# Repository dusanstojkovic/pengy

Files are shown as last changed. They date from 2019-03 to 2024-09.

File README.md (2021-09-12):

# Air Quality Monitoring



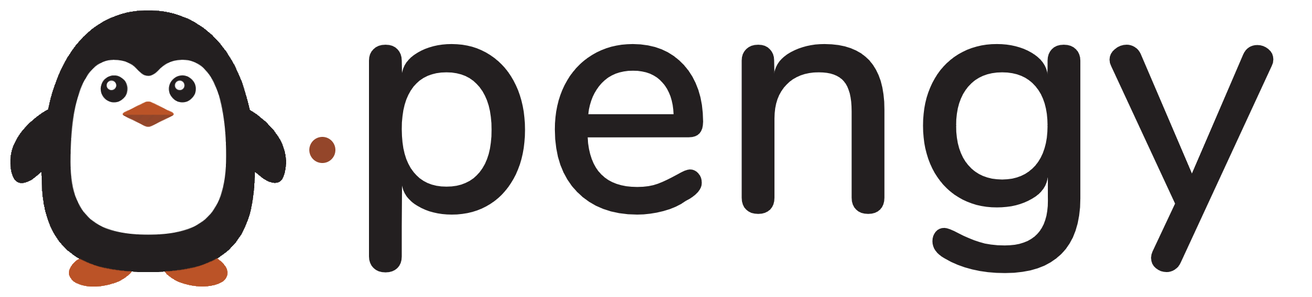
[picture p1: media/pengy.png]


**Pengy** is the system for monitoring of the air quality parameters.

The system concept and how it is build are described in the personal blog [quo.vadis.stojkovic.ch](https://quo.vadis.stojkovic.ch/air-pollution-monitor/)

## Description

The sensors on the nodes are measuring the relevant air parameters (t, RH, p, PM1.0, PM2.5, PM10 ...), data is acquired with [*Heltec CubeCell (HTCC-AB01)*](https://heltec.org/project/htcc-ab01/) device and sent using *LoRaWAN* via *The Things Network* platform. Integration to *Thingy*, as well to *Sensor Community* and *Pulse.Eco* platforms, is used for the visualization of the results.

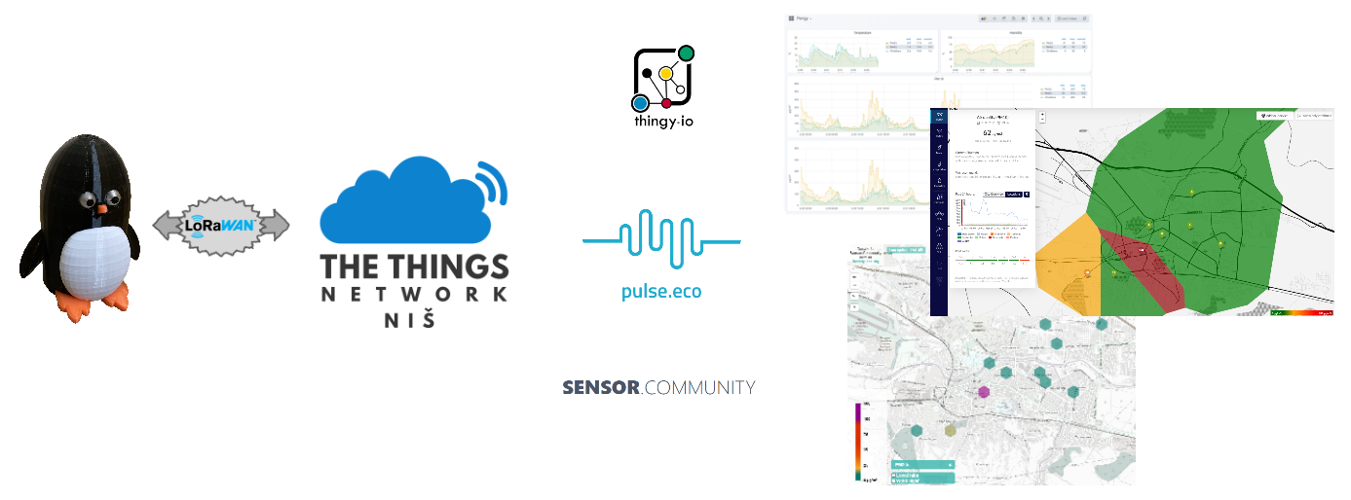
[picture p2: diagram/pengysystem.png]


Depending on the version, different sensors are used and different parameters are measured.
In the current version (2.0), parameters that are measured are: 
- air temperature (t)
- air relative humidity (RH)
- atmospheric pressure (p)
- environmental noise
- respirable (<10μm) particulate matter mass concentration (PM 10)
- fine (<2.5 μm) particulate matter mass concentration (PM 2.5)
- ultra fine (<1 μm) particulate matter mass concentration (PM 1)

using the following sensors:
- SPS30
- BME280
- MAX9814 amplifier based microphone

For the overview of the parameters and sensor used in previous version, refer to:
- version 1.5 - https://github.com/dusanstojkovic/pengy/tree/v1.5
- version 1.0 - https://github.com/dusanstojkovic/pengy/tree/v1.0

## Content

* In the folder [firmware](firmware/), you can find the latest firmware for a Pengy node
* Integration with *The Things Network* is in folder [ttn](integration/ttn/)
* Python script to push the data to *Sensor Community* platform is in folder [sensor.community](integration/sensor.community/)
* Python script to push the data to *Pulse.Eco* platform is in folder [pulse.eco](integration/pulse.eco/)
* STL files for 3D printing of the enclosure are located in folder [enclosure](enclosure/)
* Supporting pictures, drawings and diagrams you can find under [media](media/) folder
* Some additional documentation can be found under [misc](misc/) and [docs](firmware/docs/)

## Electrical schema, enclosure and assembly

There are only couples of the components that need to be soldered. Only basic soldering skills are required. Here is a simplified electrical schema:

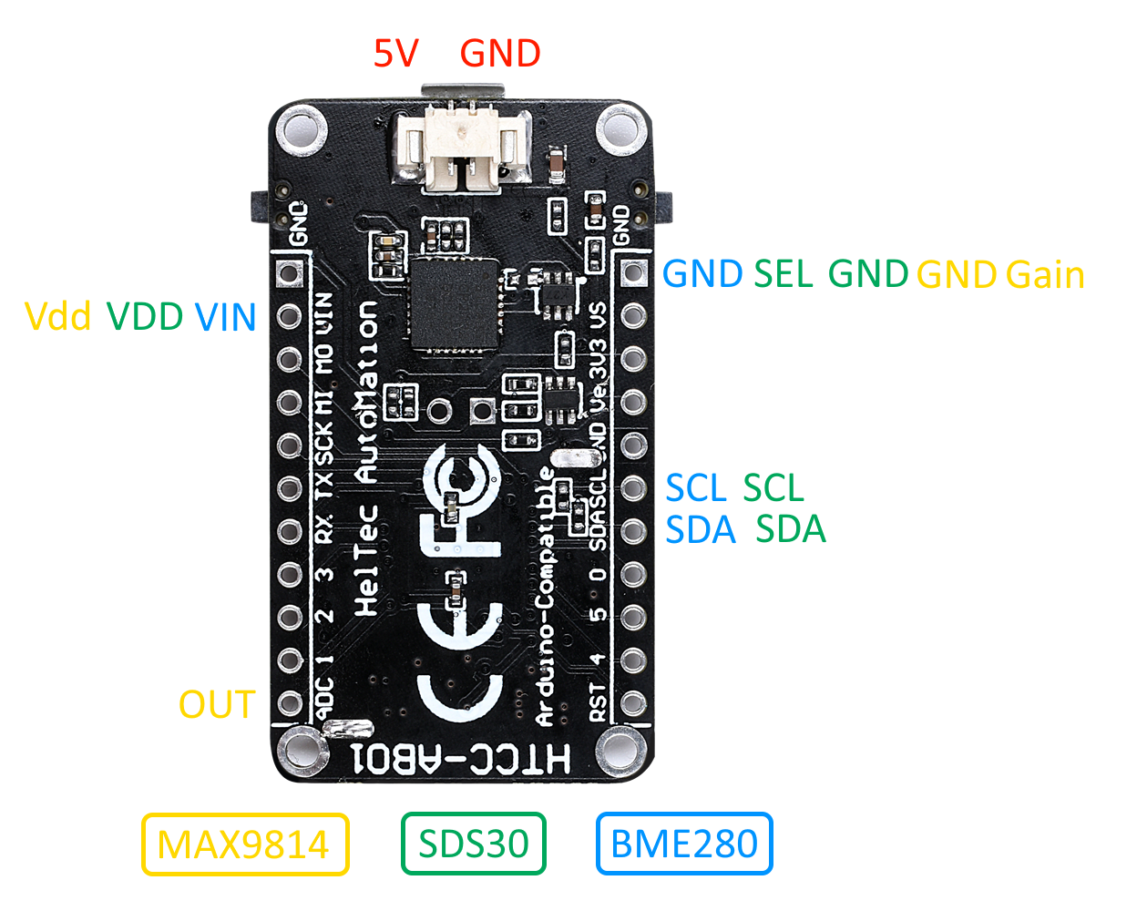
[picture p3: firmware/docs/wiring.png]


Keep in mind that 2 pull up resistors on I2C lines should be used for **SDS30**.

In this version of Pengy, there is the 3D printed enclosure available, which simplifies assembling of the whole sensor:

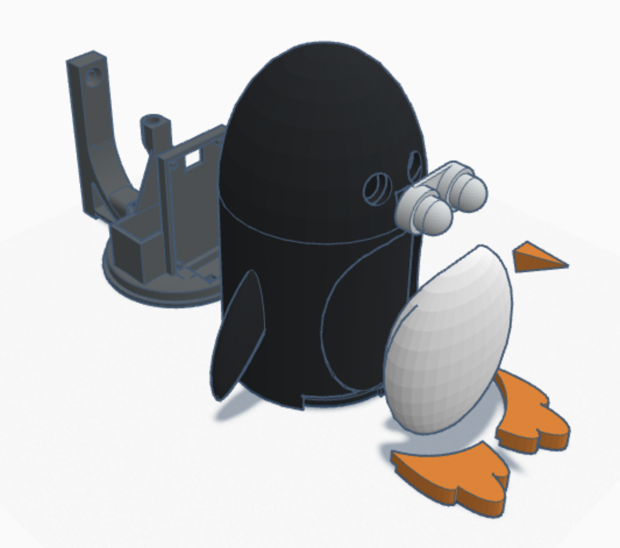
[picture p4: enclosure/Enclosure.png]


All files needed for 3D printing are located in folder  [enclosure](enclosure/). The whole design is also available on [Tinkercad](https://www.tinkercad.com/embed/jLOi4Yv6dmK) in case any modifications or adaptations needed.

The final assembly should be straightforward. There is a 'embedded' place for each electronic component modeled into the enclosure mount part. The rest of the enclosure parts can be glued together.

## EAQI - European Air Quality Index

One of the parameters that is calculated based on particulate matter concentrations measured is _European Air Quality Index_ - EAQI. More information about the index and methodology can be found http://airindex.eea.europa.eu/.

As a special feature, Pengy device would light up its eyes in the color that corresponds to the current air quality:

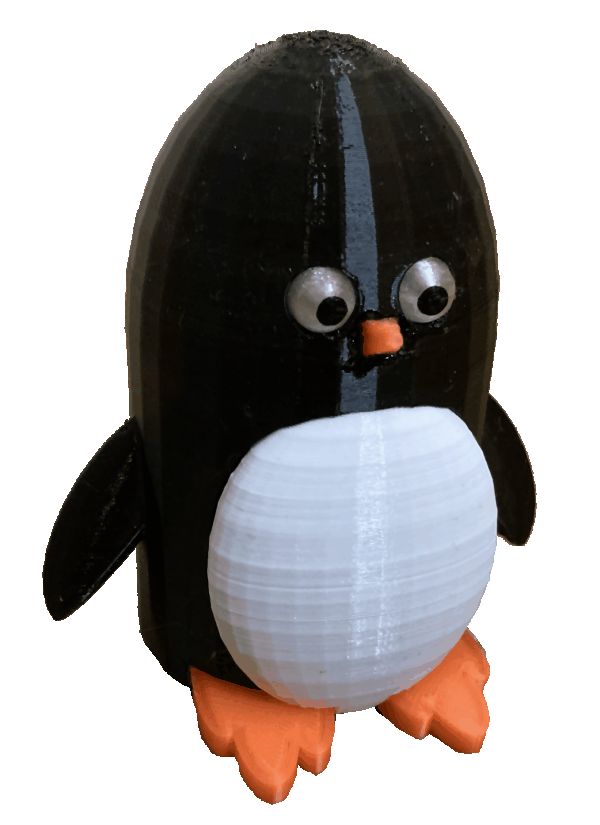
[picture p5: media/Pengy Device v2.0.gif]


## Additional information

More information regarding LoRaWAN and The Things Network can be found on their sites [LoRa Alliance](https://lora-alliance.org/about-lorawan) and [The Things Network](https://www.thethingsnetwork.org/).

More information about the contribution driven global sensor network  **Sensor Community** can be found here: [https://sensor.community/](https://sensor.community/)

More information about the environmental data crowdsourcing platform **Pulse.Eco** can be found here: [https://pulse.eco/](https://pulse.eco/)

## Notice
Due to the DIY nature of this system, the resulting measurements cannot be considered as more precise or accurate than the official measurement performed.

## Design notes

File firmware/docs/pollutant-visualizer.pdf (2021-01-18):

CHAPTER 1

INTRODUCTION

In the past decades there have been tremendous advancements in the field

of automobile industry. Usage of vehicle has been increasing rapidly. Impact on

the other side is increasing pollution level. According to European Pollution

Agency (EPA), India is generating pollution from automobiles equal to burning

of 200 million tonnes of coal every year.

This project is focussed on monitoring this pollution level to provide

awareness among people through public displays and open community maps.

System is broadly categorised into three parts: data acquisition unit, data posting

and finally data retrieving and visualizing. Data acquisition part is sub divided

into sensing unit and processing unit. In sensing unit there are two different

sensing elements which produce output levels based on gas concentrations and

suspended particles concentration (PM2.5 and PM10). As a rule of thumb,

sensors produce output in analogue form. This signal is given to microcontroller

to convert it in to digitized form using A/D converter. An algorithm applied on

these digitized data's to get the gas concentrations in terms of Parts Per Million

(PPM) and Micro gram per cubic meter (ug/m3). This sensing and converting

process is carried out for some sampling period (say 10 seconds) and average of

this is taken as result.

SIM 808 is used to post this data to cloud. It satisfies complete need of a

cellular modem because it contains on chip GPS for accessing location

information, GPRS to connect to the internet and GSM to make and receives

calls and SMS. This modem has software layer for several internet based

applications like FTP, HTTP, and TCP. So that it can access these layers by

passing AT commands. HTTP protocol is used for sending data to cloud. After

processing, the data are sent to cloud using Hyper Text Transfer Protocol. All data are sent with respect to their location where they monitored. A PHP

handler is written on the server side to handle requests that are made during data

posting. PHP handler retrieves data from HTTP requests and stores it in a

database for future analysis. An open community map with the help of Google

maps API was designed which shows the pollution level in the form of coloured

circles based on the location. Each colour defines pollution level as good,

acceptable, moderate, worst, unhealthy, and dangerous. The data are stored in a

database and it can generate periodic reports and perform some data analytics

for future prediction of pollution levels and compares it with present. In future

developments awareness can be made by public displays placed in remote

places.

CHAPTER 2

POLLUTANT VISUALIZER

### 2.1 INTRODUCTION

Air pollution level has been increasing rapidly, so there should be some

remedies made to avoid and overcome that. Fuel efficient vehicles proved in

reduction of pollution emission. One way to overcome this is to protect

ourselves. For that, people must be aware of their environment. One such

platform is bringing awareness among people. Description of this system is as

follows.

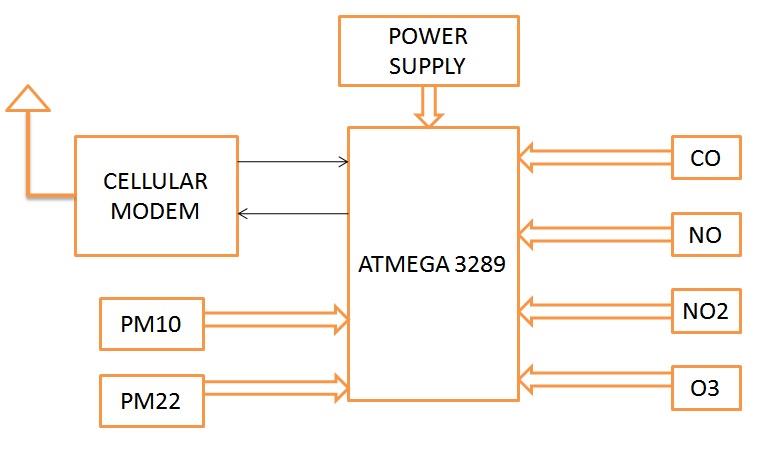
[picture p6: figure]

FIGURE 2.1 BLOCK DIAGRAM OF THE PROPOSED METHOD

### 2.1.1 DESCRIPTION

The block diagram shows ATMEGA 328 is used as a processing unit which

receives data from different sensors which produce outputs based on

concentration of gases such as Carbon Monoxide(CO), Nitrous Dioxide(NO2),

Ammonia(NH3) ,Ground ozone(O3) and suspended particles (PM2.5 and

PM10). A cellular modem SIM808 is connected to processing unit through

serial protocol (UART) and communicate with the server via this cellular

modem. A power supply unit which receives input from a battery of(6V-24V)

and uses two separate Low Drop Out (LDO) regulators for constant regulation.

One is for the cellular modem which dynamically varies the current

consumption when connected to internet and the other is for sensing and control

unit.

In hardware part, it has sensing elements which gives information about

environment (gas) in electrical form and microcontroller which does all

manipulations on acquired data. Starting with hardware part. Hardware part is

broadly categorized into five parts.

- Data Acquisition (Sensors)
- Processing unit
- Posting Unit

### 2.2 DATA ACQUISITION

The word 'electronic nose' is derived from the behaviour of today's

sensors. Humans can sense everything in physical environment. Humans have

nose which smell odours and can detect what it is. It works with the help of

olfactory glands which sense the smell and sends signal to brain through

Olfactory nerves. Brain tells you what type of smell it is by analysing that

signal. Same principle applies here. It has sensing elements which produce

signals based on gas presents in environment. Processing unit accepts these

signals, do manipulations and tells us the concentration of those gases.

### 2.3 PROCESSING UNIT

After passing signals through conditioning unit, the signal gets digitized

and processed in on-board microcontroller. ATMEGA 328 from atmel is used

as signal processing unit. It has its on-chip analog to digital converter unit with

10 bit resolution. So (0 – 5)V is scaled to (0-1024) in digital form. An algorithm

is applied on this digitized data to convert it into informative one. Several

sensors are connected to microcontroller as it is having multiple analog input

channels.

### 2.4 POSTING UNIT

Processing unit convert data into informative one like colour values based

on Air Quality index (AQI). These information will be send to our server

through a cellular modem SIM808. It is a single chip cellular modem supports

GPS, GSM and GPRS.

There is several gas sensing technologies in market. Each suits for

different applications and environments. Few of them are given below.

### 2.5 TYPES OF GAS SENSORS

Gas detectors are sensors that measure the concentration of a particular

gas in a particular area. Gas detectors are employed in many places like gas

leakage detection, indoor air quality monitoring, fire alarms etc. There are

different types of gas detectors which can measure and monitor combustible

gases, toxic and flammable gases. Carbon dioxide, carbon monoxide, Sulphur

dioxide, methane, ammonia are some common gases measured in industrial

applications.

Gas detectors:

- Electrochemical
- Metal oxide
- Infrared
- Pallister
- Semiconductor

### 2.5.1 ELECTROCHEMICAL

This method uses a chemical reaction for detecting the concentration of

gases. Its structure consist of Ion conductor sandwiched between two electrodes

(working electrode and counter electrode). When gases like carbon dioxide

(CO2) some kind of chemical reaction takes place in the working electrode. If

short occurs between working and counter electrode together then there will be

some flow of electrons between them. If connection is made through an external

wire there will also be electron flows through that. By placing an ammeter

current level which tells us the concentration of gas level is measured.

Current Flow

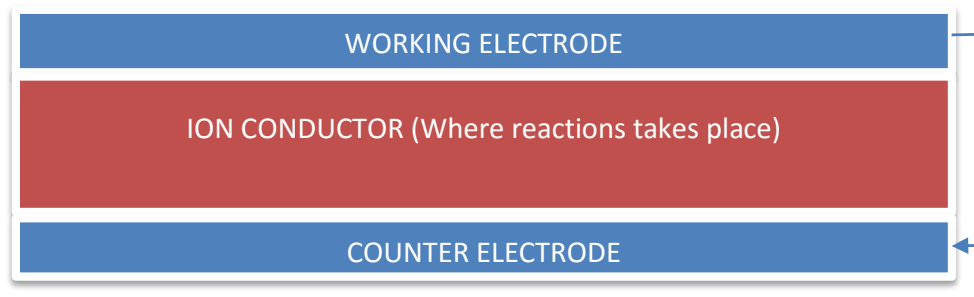
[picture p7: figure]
WORKING ELECTRODE; COUNTER ELECTRODE

FIGURE 2.2 ELECTROCHEMICAL SENSOR

### 2.5.2 METAL OXIDE

Tin oxide is used as a reactant and its surface is filled with absorbed

oxygen. The complete arrangement is placed above an alumina. In clean air

oxygen prevents the electron flow through this tin layer as it absorbs it. When

ION CONDUCTOR (Where reactions takes place) AMMETER any gas falls, reaction takes place and this absorb oxygen gets reduced. So

electrons starts to flow and it can be measured by placing an ammeter or load.

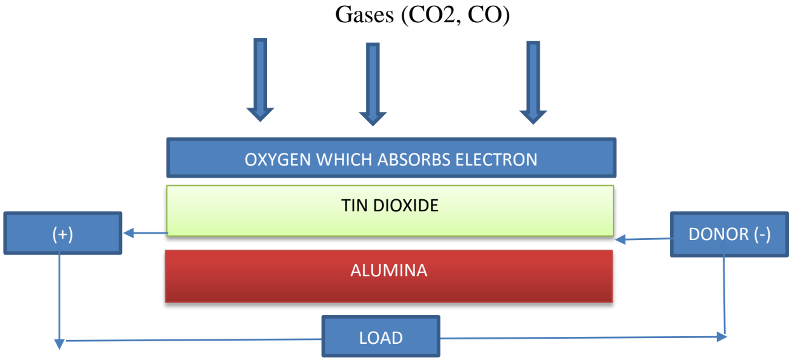
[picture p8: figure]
Gases (CO2, CO); OXYGEN WHICH ABSORBS ELECTRON; TIN DIOXIDE; ALUMINA; DONOR (-); LOAD

FIGURE 2.3 METAL OXIDE SENSOR

### 2.5.3 INFRARED (IR)

This method uses optical reflection technique to measure the gas

concentration level. Each gas absorb light of some wavelength. It depends on

type of gas that are going to measure. It consists of an infrared led and

photodiode arrangement. In clean air all the light get reflected back to

photodiode. When some gas falls on it then there will be some change in

received light and this difference in signal tells us the concentration of gases.

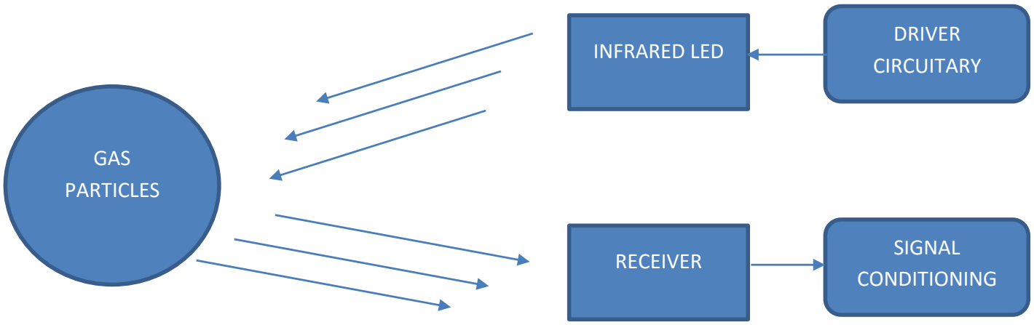
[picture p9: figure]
INFRARED LED; RECEIVER; GAS PARTICLES; DRIVER CIRCUITARY; SIGNAL CONDITIONING

FIGURE 2.4 INFRARED SENSOR

### 2.5.4 PALLISTER AND SEMICONDUCTOR

In this the detecting element consists of a pellet and a resistor. Selection

of a pellet depends on the gas that is going to be measured. Two beads called

active bead and reference bead. When gas comes in contact with these beads

active bead burns the gas and produces some heat which changes resistance.

Then it is compared with reference bead to determine the concentration of gas

applied.

Semiconductor method works on the same principle as pallister. Some

resistance change represent the concentration of applied gas. Tin dioxide is the

most common reactive material used in semiconductors. Common resistance

used with this type of sensor is 50 kilo ohm.

Among these types of sensors in the market Metal Oxide type is chosen

because it’s settling time is very fast and consumes very less power compared to

other types of sensors. Its reaction time is also too fast.

### 2.6 MICS 6814

Recent sensing technology utilize the power of metal oxides with the help

of semiconductor technology. Metal Oxides are Nano particles which today

takes place in most of Integrated Circuit fabrication technology. Micro Electric

Mechanical Systems (MEMS) mostly uses metal oxide in its fabrication in order

to decrease size and power consumption. MICS 6814 from SGX sensor tech is a

type of Metal Oxide type sensor which uses Zinc Oxide as a sensing element.

Working of metal oxide type gas sensing is show in picture below.

Gases (CO2, CO)

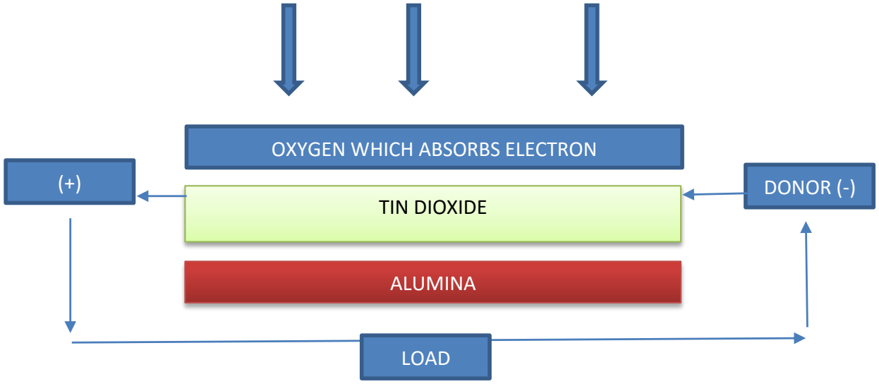
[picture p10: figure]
OXYGEN WHICH ABSORBS ELECTRON; TIN DIOXIDE; ALUMINA; DONOR (-); LOAD

FIGURE 2.5 MICS 6814

It consist of Zinc oxide which does not allow any current to pass through

it when pure oxygen falls on that. That is the resistance is infinity. When any

contaminated gas falls on that, amount of current which starts flow through that

and is directly proportional to concentration of fallen gas. By having different

sensing elements (heating elements) different type of gas concentration is

measured. MICS 6814 uses three different sensing elements in a single package

which can measure gases like carbon monoxide, nitrous dioxide, ammonia.

Heating element or substrate (RS) which combines with load resistor (RL)

forms a voltage divider. Heating element acts as a variable resistor based on

concentration of gases fallen. Output voltage swing varies depends on variable

resistor. Data manipulation section will provides enough information about how

these values are converted into microgram per cubic meter. Sensing element RS

which is a variable resistance and RO which is the resistance value measure

during calibration. Ratio of variable resistance (RS) to Initial resistance (RO)

tells us concentration of gas levels. Each sensing element has its own variable

resistance and calibration resistance which produces different ratio levels.

The figure below you the working principle of MICS6814, it contains

three different sensing elements (heating elements) for sensing the levels of

Carbon Monoxide, Nitrous Dioxide and ammonia. Each sensing element acts as

a variable resistor. It needs a load resistor to act as an active voltage divider

network. Thus output voltage varies proportional to the resistance of sensing

element.

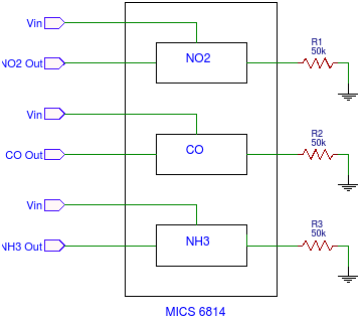
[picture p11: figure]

FIGURE 2.6 MICS WORKING

### 2.6.1 PERFORMANCE CHARACTERISTICS OF MICS 6814

Parameters which define sensitivity are RO (sensing resistance in air) and

RS (Sensing element). Sensitivity factor of variable resistance is given as SR.

Following table shows the specification of CO sensing element.

Sensing characteristics of CO sensor

Table 2.1 CO CHARACTERESTICS

Characteristic of CO sensor | Symbol | Typical | Minimum | Maximum | Unit
Sensing resistance in air | RO | - | 100 | 1500 | K ohm
Typical CO detection range | FS | - | 1 | 1000 | PPM
Sensitivity factor | SR | - | 1.2 | 50 | -

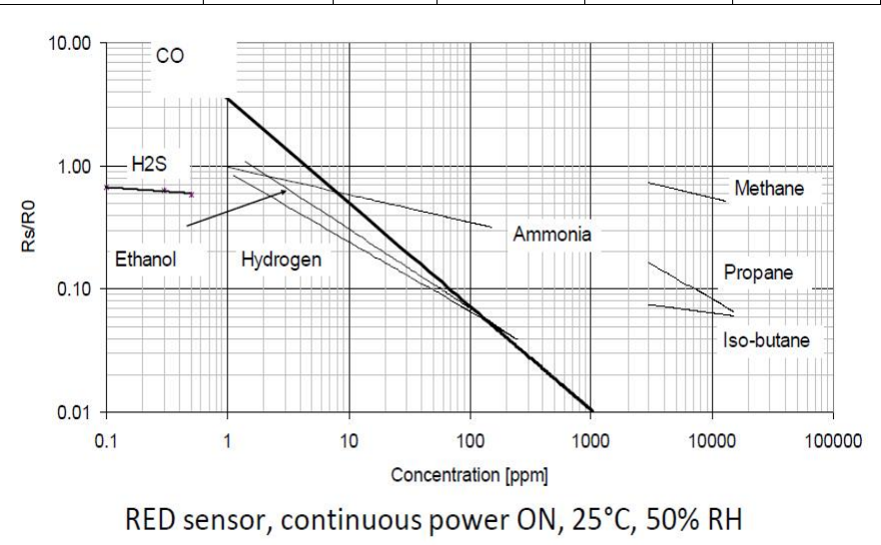
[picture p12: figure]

FIGURE 2.7 CO CHARACTERESTICS

Sensing characteristics of NO2 sensor

Parameters which define sensitivity are RO (sensing resistance in air) and

RS (Sensing element). Sensitivity factor of variable resistance is given as SR.

Following table shows the specification of NO2 sensing element.

Table 2.2 NO2 CHARACTERESTICS

Characteristic of CO sensor | Symbol | Typical | Minimum | Maximum | Unit
Sensing resistance in air | RO | - | 0.8 | 20 | K ohm
Typical CO detection range | FS | - | 0.05 | 10 | PPM
Sensitivity factor | SR | - | 2 | - | -

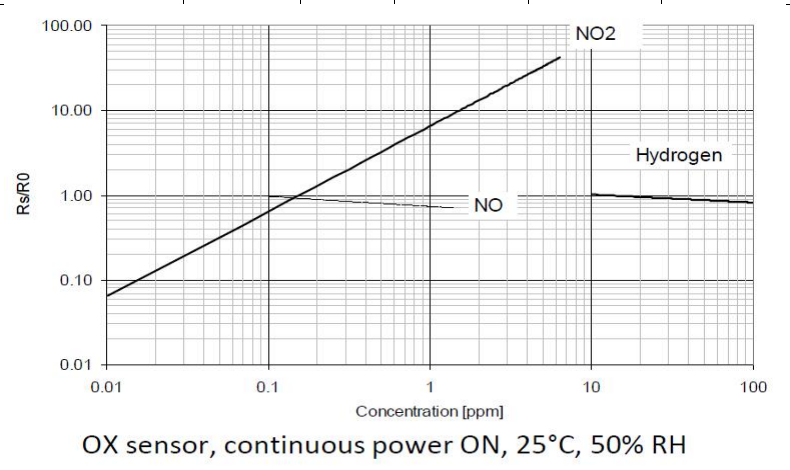
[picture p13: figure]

FIGURE 2.8 NO2 CHARACTERESTICS

Sensing characteristics of NH3 sensor

Parameters which define sensitivity are RO (sensing resistance in air) and

RS (Sensing element). Sensitivity factor of variable resistance is given as SR.

Following table shows the specification of NH3 sensing element.

Table 2.3 NH3 CHARACTERESTICS

Characteristic of CO sensor | Symbol | Typical | Minimum | Maximum | Unit
Sensing resistance in air | RO | - | 10 | 1500 | K ohm
Typical CO detection range | FS | - | 1 | 300 | PPM
Sensitivity factor | SR | - | 1.5 | 15 | -

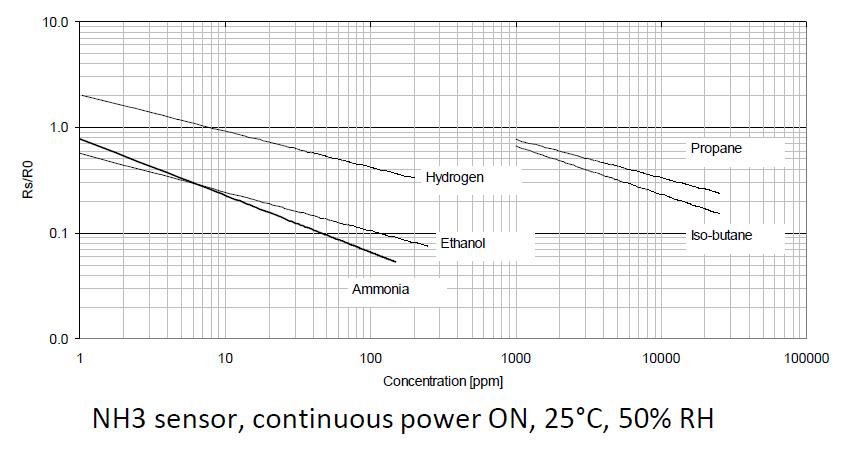
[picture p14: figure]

FIGURE 2.9 NH3 CHARACTERESTICS

Tables shows the detection range and sensitivity of each sensing

elements. Ro value can be taken from calibrating the sensor and Rs values is a

run time variable resistance value. Ratio of this will tells us the concentration.

Graphs shows how resistance ratio is related to gas concentrations in PPM.Line

equation for these graphs to find the relationship between ratio and PPM values

is found. By passing RS/RO into that line equation, concentration level in PPM

will be obtained.

### 2.6.2 ESTIMATION OF SENSITIVITY

First take two known points from the line to form an equation. Pass X and

Y values into line equation Y=Mx+C. Then by solving two known equations,

unknown value M that is slope can be found. Then by re arranging equation X

is found which is PPM in above graph by passing Y as Rs/Ro above.

Above process is carried for every sampling window and averaged value

is passed to following equation which results pollution level in microgram per

cubic meter.

PPB = PPM * 1000 | → Eq 2.1

Microgram per cubic meter = (PPM * 12.187 * M) / (273.15 + C) → Eq 2.2

Where,

M - Single molecule weight of gas.

C – Temperature in Degree Celsius.

### 2.6.3 MICS 6814 MODULE

A module from MGsuper labs is used which has it's on board controller to

receive analogue output from sensor. An algorithm which converts this raw data

into Parts per Million levels by having pre analysed data's provided by sensor

manufacturer. PPM values are taken from that module via Inter Integrated

Circuit as a communication interface. Complete block diagram of our module is

shown below.

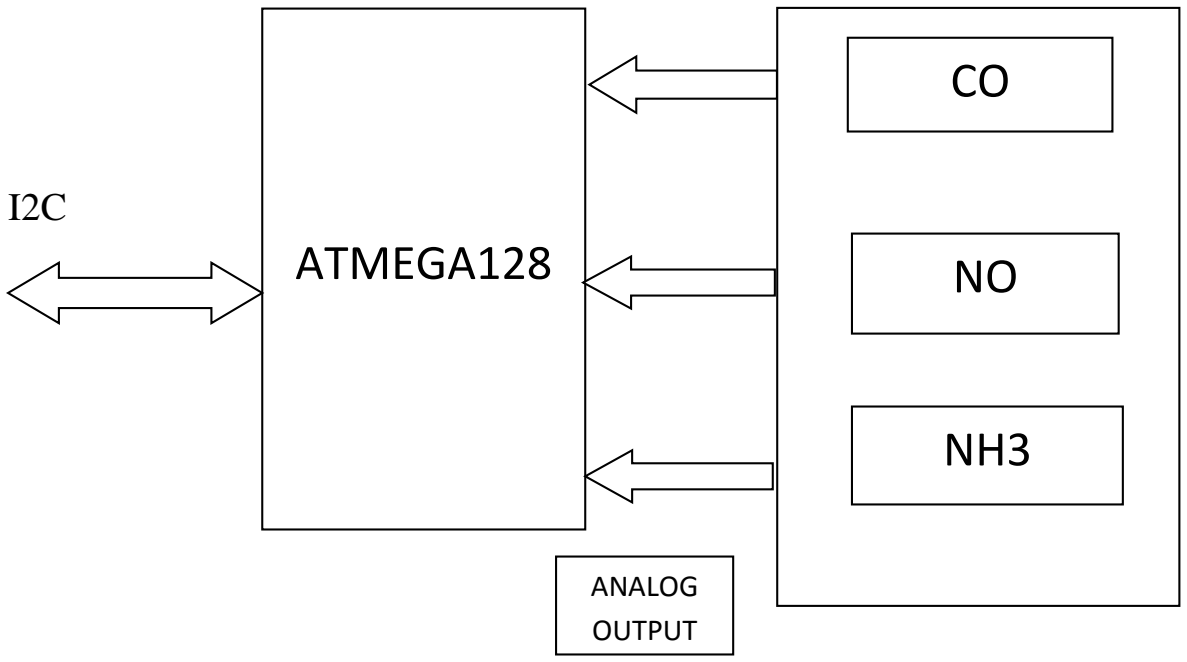
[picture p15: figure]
ATMEGA128; ANALOG OUTPUT

FIGURE 2.10 MICS 6814 MODULE DIAGRAM

ATMEGA 128 is an on board controller which continuously tells us the

concentration of sensed gases from device start up. It applies an algorithm that

will be discussed in software section to result the required values for further

manipulations. Data output is taken through I2C protocol for further processing.

### 2.7 MQ131

MQ131, a semiconductor type sensor capable of sensing ground ozone

level. Ozone present in ground will get react with hydrocarbons which causes

lung and asthma problems. It consist of a heating element which gets react with

ozone and changes its resistance proportional to ozone level present. The

working principle is as follows.

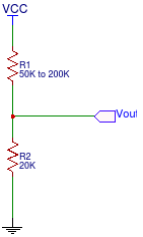
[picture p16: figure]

FIGURE 2.11 MQ131 WORKING PRICIPLE

Sensing element R1 varies between 50K - 200K. By connecting a load

resistor of 20K, the network acts as a voltage divider. So output voltage varies

depends on the resistance variation of this resistor R1. Specifications are given

below.

### 2.7.1 ELECTRICAL CHARACTERISTICS OF MQ131

TABLE 2.4 ELECTRICAL CHARACTERISTICS OF MQ131

Symbol | Parameter name | Level | Remarks
VH | Heating Voltage | 6V | DC
RL | Load Resistance | Variable | -

### 2.8 PARTICULATE MATTER MEASURING PRINCIPLE

Particulate matter otherwise called as suspended particles can be found in

air. They are in the form of dust, soot, smoke which cannot be seen by naked

eye. It contains two types of matters. One of them are ‘inhalable matters’ which

are less than 10 micro meter in size. Particles less than 2.5 micro meter comes

under ‘fine particle’ which can easily pass through deep lungs and cause health

problems. There are various techniques available in market for this particulate

matter measurement. Optical measurement is one of its type. It is very simple to

implement with high accuracy. It can be built with an Infrared transmitter, a

photodiode and its signal conditioning circuit.

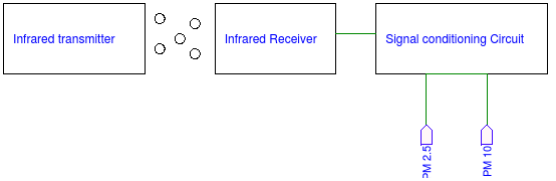
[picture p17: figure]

FIGURE 2.12 DUST SENSOR WORKING PRINCIPLE

Above block diagram simply explain working principle of optical type

particulate measurement technique. It consist of an Infrared transmitter which is

driven by constant current. Whenever dust particles comes in line of

transmission, then lights gets blocked. Photodiode receives this refracted light

and convert it into corresponding voltage by Transimpedance amplifier.

Converted voltage is compared with pre calibrated threshold voltage levels to

produce Pulse width Modulation (PWM) for both 2.5 and 10 micro meter dust

particles. Because light blocked by 2.5 micro meter particle is less than 10

micro meter particle. So two different threshold levels are used to differentiate

these two dust particles.

### 2.8.1 DUST SENSOR SM-PWM

Sm_PWM is a dust sensor that detects the dust particle concentration in

air by using optical sensing method. An infrared light emitting diode and a

photo sensor are optically arranged in the device. The photo sensor detects the

reflected light by dust particle in air. It can detect the small particles like

cigarette smoke and it can distinguish particles like smoke from large dust

particle by use of pulse pattern. Picture below show the working principle.

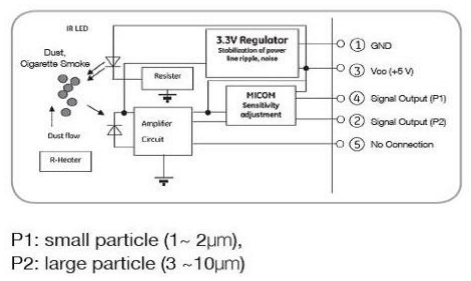
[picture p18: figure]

FIGURE 2.13 SM-PWM WORKING PRINCIPLE

The devices outputs two dust levels as a pulse modulated signal. Low

pulse period indicates the presence of dust particle. So for a sampling window

of 10 seconds time occupied by low pulse will tell you the percentage of dust

level present. Algorithm is discussed in software section later.

### 2.8.2 FEATURES

- Compact size, Light weight
- PWM output (Active low)
- Distinguishes small particles of cigarette smoke from large particles
- Low pulse is proportional to particle size
- Le.8.2 ad free and ROHS directive compliant

### 2.8.3 APPLICATIONS

- Detection of dust in air for indoor and outdoor air quality monitoring
- Air cleaners, Air purifiers, Air conditioners.
- Smoke type fire alarm.

### 2.8.4 ELECTRICAL CHARACTERISTICS

TABLE 2.5 ELECTRICAL CHARACTERISTICS OF DUST SENSOR

Parameter | Symbol | Rating
Supply Voltage | VCC | 0 – 7V
Operating Temperature | Toper | -10 – 70

### 2.9 MICROCONTROLLER ATMEGA 328

The ATmega48A/PA/88A/PA/168A/PA/328/P is a low-power CMOS 8-

bit microcontroller based on the AVR enhanced RISC architecture. By

executing | powerful | instructions | in | a | single | clock | cycle, | the

ATmega48A/PA/88A/PA/168A/PA/328/P achieves throughputs approaching 1

MIPS per MHz allowing the system designer to optimize power consumption

versus processing speed.

The AVR core combines a rich instruction set with 32 general purpose

working registers. All the 32 registers are directly connected to the Arithmetic

Logic Unit (ALU), allowing two independent registers to be accessed in one

single instruction executed in one clock cycle. The resulting architecture is more

code efficient while achieving throughputs up to ten times faster than

conventional CISC microcontrollers.

The ATmega48A/PA/88A/PA/168A/PA/328/P provides the following

features: 4K/8Kbytes of In-System Programmable Flash with Read-While-

Write capabilities, 256/512/512/1Kbytes EEPROM, 512/1K/1K/2Kbytes

SRAM, 23 general purpose I/O lines, 32 general purpose working registers,

three flexible Timer/Counters with compare modes, internal and external

interrupts, a serial programmable USART, a byte-oriented 2-wire Serial

Interface, an SPI serial port, a 6-channel 10-bit ADC (8 channels in TQFP and

QFN/MLF packages), a programmable Watchdog Timer with internal

Oscillator, and five software selectable power saving modes. The Idle mode

stops the CPU while allowing the SRAM, Timer/Counters, USART, 2-wire

Serial Interface, SPI port, and interrupt system to continue functioning. The

Power-down mode saves the register contents but freezes the Oscillator,

disabling all other chip functions until the next interrupt or hardware reset. In

Power-save mode, the asynchronous timer continues to run, allowing the user to maintain a timer base while the rest of the device is sleeping. The ADC Noise

Reduction mode stops the CPU and all I/O modules except asynchronous timer

and ADC, to minimize switching noise during ADC conversions. In Standby

mode, the crystal/resonator Oscillator is running while the rest of the device is

sleeping. This allows very fast start-up combined with low power consumption.

Atmel® offers the QTouch® library for embedding capacitive touch buttons,

sliders and wheels functionality into AVR® microcontrollers.

The patented charge-transfer signal acquisition offers robust sensing and

includes fully debounced reporting of touch keys and includes Adjacent Key

Suppression® (AKS™) technology for unambiguous detection of key events.

The easy-to-use QTouch Suite tool chain allows you to explore, develop and

debug your own touch applications. The device is manufactured using Atmel’s

high density non-volatile memory technology. The On-chip ISP Flash allows

the program memory to be reprogrammed In-System through an SPI serial

interface, by a conventional non-volatile memory programmer, or by an On-

chip Boot program running on the AV\R core. The Boot program can use any

interface to download the application program in the Application Flash

memory. Software in the Boot Flash section will continue to run while the

Application Flash section is updated, providing true Read While-Write

operation. By combining an 8-bit RISC CPU with In-System Self-

Programmable | Flash | on | a | monolithic | chip, | the | Atmel

ATmega48A/PA/88A/PA/168A/PA/328/P is a powerful microcontroller that

provides a highly flexible and cost effective solution to many embedded control

applications. The ATmega48A/PA/88A/PA/168A/PA/328/P AVR is supported

with a full suite of program and system development tools including: C

Compilers, Macro Assemblers, Program Debugger/Simulators, In-Circuit

Emulators, and Evaluation kits.

### 2.9.1 ARCHITECTURE

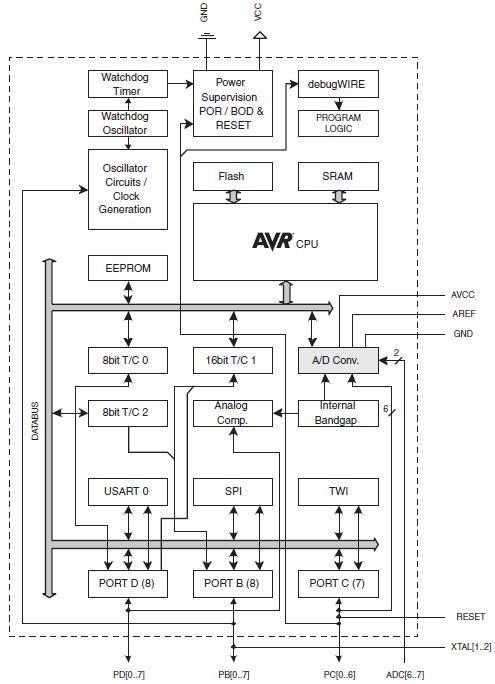
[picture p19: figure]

FIGURE 2.14 ATMEGA 328P ARCHITECTURE

### 2.9.2 ANALOG TO DIGITAL CONVERTER

To convert analog quantities into digital domain, A/D converters play a

major role. ATMEGA328 has a 10 bit, programmable sampling rate analog to

digital converter. It has eight analog input channels to interface as many

sensors. It has a full scale input of 5V and optional voltage reference pin to vary

the full scale input. Its output scale is from 0 to 1024. Four different channels

have been used to interface four different gas sensors. Each channel is

converted sequentially.

### 2.9.3 FEATURES

- High performance, Low power 8 bit microcontroller family
- Advanced RISC architecture
- 131 powerful instructions
- 32x8 general purpose working registers
- Fully static operation
- Up to 20 MIPS
- 32 Kilo bytes of flash memory
- 256 bytes of EEPROM
- 512 bytes of SRAM
- Programmable serial USART
- Master Slave SPI interface
- Six PWM channels
- Six channel 10 bit Analog to Digital converters
- On chip Analog converter
- Interrupt and wake up
- Power on reset
- Brown out reset
- Operating range – 1.8V to 5.5 V

- Operating frequency - 4 to 20 MHz

### 2.10 SIM808

SIM808 module is a complete Quad band GSM/GPRS module which

combines GPS technology for satellite navigation. The compact design which

integrated GPRS and GPS in a SMT package will significantly save both time

and costs for customers to develop GPS enabled applications. Featuring an

industry standard interface and GPS function, it allows variable assets to be

tracked seamlessly at any location and anytime with signal coverage.

Here SIM808 is used as a gateway to connect to our server. Free hosting

service from hostinger is used. After collecting and processing data that have to

be posted it into database for further processing. Here SIM808, a GPS, GPRS

and GSM chipset connects to internet through which data is posted to cloud.

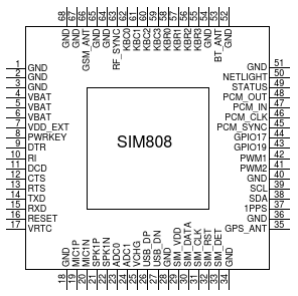
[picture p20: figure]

FIGURE 2.15 SIM808 PINOUT

Communication between SIM808 and microcontroller via Universal

Asynchronous Receiver Transmitter (UART). With the help of AT commands

features of this chipset is accessed and controlled.

SIM808 has following functional parts:

- The GSM baseband engine
- The GPS engine
- Flash memory
- The GSM radio frequency part
- The antenna interface
- The other interfaces

### 2.10.1 AT COMMANDS USED

COMMAND | DESCRIPTION
AT+CGPSPWR | GPS POWER CONTROL
AT+CGPSRST | GPS RESET MODE (COLD/HOT/WARM)
AT+CGPSINF | GET CURRENT GPS LOCATION INFO
AT+CGPSOUT | GET NMEA DATA OUTPUT CONTROL
AT+CGPSSTATUS | GPS FIX STATUS
AT+SAPBR=3,1”Contype”,”GPRS” AT+SAPBR=3,1”APN”,”CMNET” | CONFIGURE BEARER PROFILE 1
AT+SAPBR=1,1 | TO OPEN A GPS CONTEXT
AT+SAPBR=2,1 | TO QUERY THE GPS CONTEXT
AT+SAPBR=0,1 | TO CLOSE THE GPS CONTEXT
AT+HTTPINIT | INIT HTTP SERVICE
AT+HTTPPARA=”CID”,1 AT+HTTPPARA=”URL”,”WWW.XYZ.COM | SET PARAMETERS FOR HTTP SESSIONS

AT+HTTPACTION=0 | GET SESSION START
AT+HTTPREAD | READ THE DATA OF HTTP SERVER
AT+HTTPTERM | TERMINATE HTTP SERVICE

SIM808 module supports transfer protocols like FTP, HTTP for

transferring of files in machine to machine communication. Data is sent via

Hyper Text Transfer Protocol. Problem faced is when using this protocol is that

the sent data will be reflected at server side for a fraction of second. So instant

data is taken and store it in any other file. A database is used to store our data’s.

A PHP handler reads the data from HTTP and store it in local variables. Then

connect to our database and store these values. Extracting data from Url is as

follows.

$_Variable_1 = $_GET[“variable_1];

$_Variable_2 = $_GET[“variable_2];

Left hand side variable are PH variables which temporarily stores the

extracted values. GET is a keyword to indicate that data was sent using which

method. Variables inside square braces must be the same name as that are sent

while it is sent. PHP variables now holds the values of that key names. Finally

posting data to database.

### 2.11 POWER SUPPLY

In order to operate the circuit properly good regulated power supply is

provided. There are varieties of voltage regulators in market. They are linear

regulators, low drop out regulators and switched regulators. Linear regulators

often packaged as a fixed voltage regulator which means it has a constant

voltage drop of 1.25V to 1.75V. This provides the perfect regulation because of

laser tuned components presents in Integrated circuit. But it is not suitable when

input voltage approaches near the output voltage. For example 6V battery is

needed to generate 5V for our circuit to operate properly. It cannot be possible

by using fixed voltage regulators because, the drop 1.25 is fixed. So it can only

generate a maximum of 4.5 to 4.75 at the output. It also produces more heat due

to power dissipation. Low drop out regulators comes as variable regulators and

it can produce required output voltage when input voltage appears near. Any

required voltage can be regulated by just having two external resistors and two

filter capacitors. Both linear and low drop out regulators are not efficient in

battery operated applications because of high power dissipation. Switched

regulators are otherwise called as buck converters does DC to DC conversion by

switching operation provides very high efficiency. Cost of buck converters are

high when compared two linear and low drop out regulators.

Here two low drop out regulators are to provide separate supply for

microcontroller and sensors. The output voltage can be programmed simply

using the external resistors. Formula for calculating the resistor values.

Vout = (1 + R2/R1) * 1.25 | →Eq 2.3

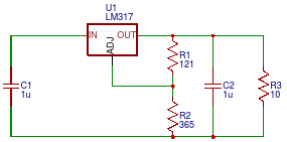
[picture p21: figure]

FIGURE 2.16 LDO CIRCUIT

For 5V output:

R1 = 121 ohm

R2 = 365 ohm

Vout = (1 + 365/121) * 1.25

### 2.12 TOOLS USED

Development phases include hardware simulation, schematic and layout design, power supply design. Following are the tools used for simulation and designing.

### 2.12.1 ALTIUM DESIGNER

Altium Designer is an electronic design automation (https://en.wikipedia.org/wiki/Electronic_design_automation) software package

for printed circuit board, (https://en.wikipedia.org/wiki/Printed_circuit_board) FPGA (https://en.wikipedia.org/wiki/FPGA) and software design, and associated library and

release management automation. It is developed and marketed by Altium

Limited (https://en.wikipedia.org/wiki/Altium_Limited) of Australia.

Schematic capture module provides electronic circuit editing functionality,

including:

- Component library management
- Schematic document editing (component placement, connectivity editing

and design rules definition)

- | Integration | with | several component | distributors (https://en.wikipedia.org/wiki/Category:Electronic_component_distributors) allows | search | for
components and access to manufacturer's data[3] (https://en.wikipedia.org/wiki/Altium_Designer#cite_note-3)
- SPICE mixed-signal circuit simulation
- Pre-layout signal integrity analysis
- Netlist export
- Reporting and BoM facilities
- Multi-channel, hierarchical schematics and design re-use

SCHEMATIC

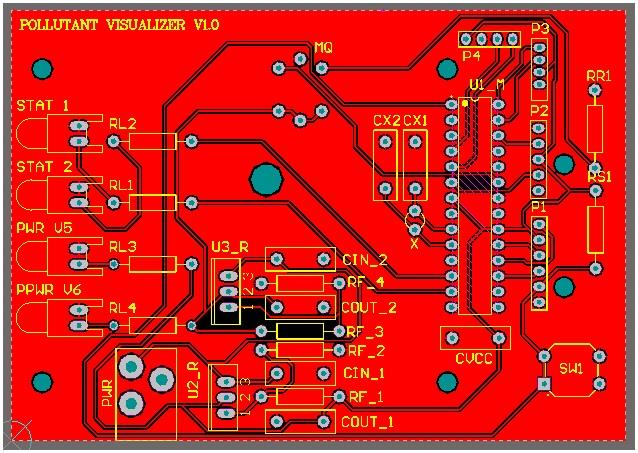
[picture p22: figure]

FIGURE 2.17 PCB LAYOUT

### 2.12.2 LTSPICE

LTspice IV is a high performance SPICE simulator, schematic capture

and waveform viewer with enhancements and models for easing the simulation

of switching regulators. Our enhancements to SPICE have made simulating

switching regulators extremely fast compared to normal SPICE simulators,

allowing the user to view waveforms for most switching regulators in just a few

minutes. Included in this download are LTspice IV, Macro Models for 80% of

Linear Technology's switching regulators, over 200 op amp models, as well as

resistors, transistors and MOSFET models.

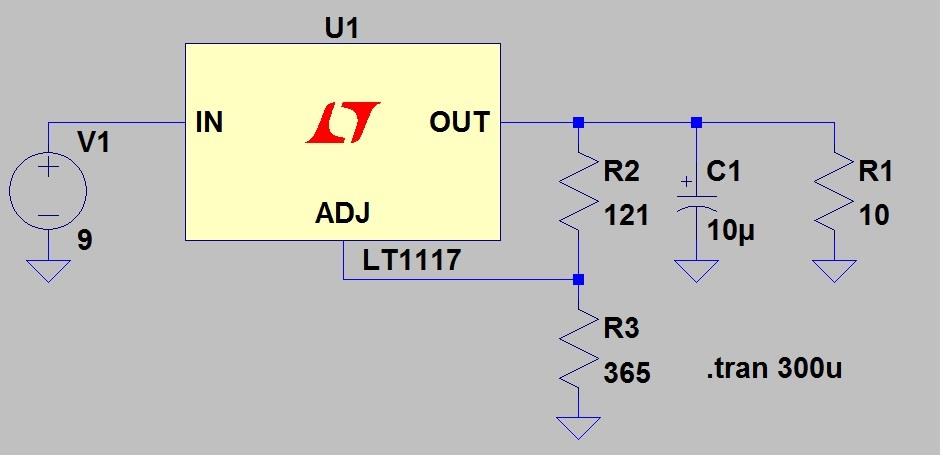
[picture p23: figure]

FIGURE 2.18 LTSPICE SCHEMATIC

### 2.12.3 PROTEUS

The Proteus Design Suite is an Electronic Design Automation (EDA) tool

including schematic capture, simulation and PCB Layout modules. It is

developed in Yorkshire, England by Labcenter Electronics Ltd with offices in

North America and several overseas sales channels. The software runs on the Windows (https://en.wikipedia.org/wiki/Microsoft_Windows) operating system and is available in English, French, Spanish and

Chinese languages. The Proteus Design Suite is a Windows application for

schematic capture, simulation, and PCB layout design. It can be purchased in

many configurations, depending on the size of designs being produced and the

requirements for microcontroller simulation. All PCB Design products include

an auto router and basic mixed mode SPICE simulation capabilities. Schematic

capture in the Proteus Design Suite is used for both the simulation of designs

and as the design phase of a PCB layout project. It is therefore a core

component and is included with all product configurations

The micro-controller simulation in Proteus works by applying either a hex

file or a debug file to the microcontroller part on the schematic. It is then co-

simulated along with any analog and digital electronics connected to it. This

enables it's used in a broad spectrum of project prototyping in areas such as

motor control, temperature control and user interface design. It also finds use in

the general hobbyist community and, since no hardware is required, is

convenient to use as a training or teaching tool. Support is available for co-

simulation of:

- Microchip Technologies (https://en.wikipedia.org/wiki/Microchip_Technology) PIC10, PIC12, PIC16, PIC18, PIC24, dsPIC33

Microcontrollers.

- Atmel (https://en.wikipedia.org/wiki/Atmel) AVR (and Arduino), (https://en.wikipedia.org/wiki/Arduino) 8051 and ARM Cortex-M3 (https://en.wikipedia.org/wiki/ARM_Cortex-M#Cortex-M3) Microcontrollers
- | NXP (https://en.wikipedia.org/wiki/NXP_Semiconductors) 8051, | ARM7, ARM | Cortex-M0 (https://en.wikipedia.org/wiki/ARM_Cortex-M#Cortex-M0) and | ARM | Cortex-M3

Microcontrollers.

- Texas Instruments (https://en.wikipedia.org/wiki/Texas_Instruments) MSP430, PICCOLO DSP and ARM Cortex-M3

Microcontrollers.

- Parallax Basic Stamp, Freescale HC11, 8086 Microcontrollers

The PCB Layout module is automatically given connectivity information in

the form of a net list (https://en.wikipedia.org/wiki/Netlist) from the schematic capture module. It applies this

information, together with the user specified design rules (https://en.wikipedia.org/wiki/Design_rule_checking) and various design

automation tools, to assist with error free board design. Design Rule Checking

does not include high speed design constraints. PCB's of up to 16 copper layers

can be produced with design size limited by product configuration

CHAPTER 3

SOFTWARE IMPLEMENTATION

This section will discuss deep into the software development in this

section. This section comprised of algorithm development for data posting,

database management, data retrieval and Google maps API.

### 3.1 ALGORITHM

The flow chart of our algorithm is shown in figure. As the process

involves network connectivity it needs some important thing that has to be done

at device start up. The start-up process includes connecting the device to the

network. To do that necessary AT commands are to be passed to the cellular

modem. For each command modem replies about the success or failure of that

command. For example, AT is a command used to verify whether the device is

alive or not. Modem replies "OK" if it's working else its reply will be

"ERROR". Different responses from the modem for various commands will

come. These replies indicate that whether the modem is connected to network or

not. Hence, all other process will be in a queue until the modem gets connected

to network.

Second process is starting data service to communicate with server. It

involves similar process like network connectivity but it needs some network

settings like APN, username and password. All these settings are done by AT

commands. As the process involves of grabbing location co-ordinates the device

has to get lock with GPS satellites which comes third in a queue. Different

status led's shows the status of network connectivity, data services, and GPS.

The above mentioned three processes are mandatory for proper operation.

All other manipulations will be kept in a queue. After successful start up the key

process begins and it is nothing but data acquisition and manipulating. The first

sampling window is for the calibration of sensors. Here the main acquisition begins. The result of this process will be gas concentrations in PPM and

Microgram per cubic meter. This process continuous for every 10 seconds and

average those data's. The next part plays an important role in cloud connectivity.

The accumulated or averaged values are sent to our server with the help of

Hyper Text Transfer Protocol. As mentioned earlier our modem has software

layer for HTTP, FTP, and TCP etc. HTTP can transmit or receive simple text

data's. More about data posting will be discussed in a separate section. The

start-up process can stop the main process at any time via interrupts if there is

any disconnectivity problems occurred in data or network connectivity. The

loop from data acquisition to data posting continuous forever.

HTTP supports two methods in data posting. GET and POST method.

Here GET method is used to pot data’s to server. The syntax of posting data via

HTTP is below.

http://www.xyz.com/?variable_1=value1&variable_2=value2

HTTP denotes the type of transfer protocol . Our domain name comes

after that. A question mark symbol (?) denotes the start of data’s. Key and data

is the format used. Key is used while retrieving data in server side and values is

run time value.

### 3.1.1 FLOW CHART

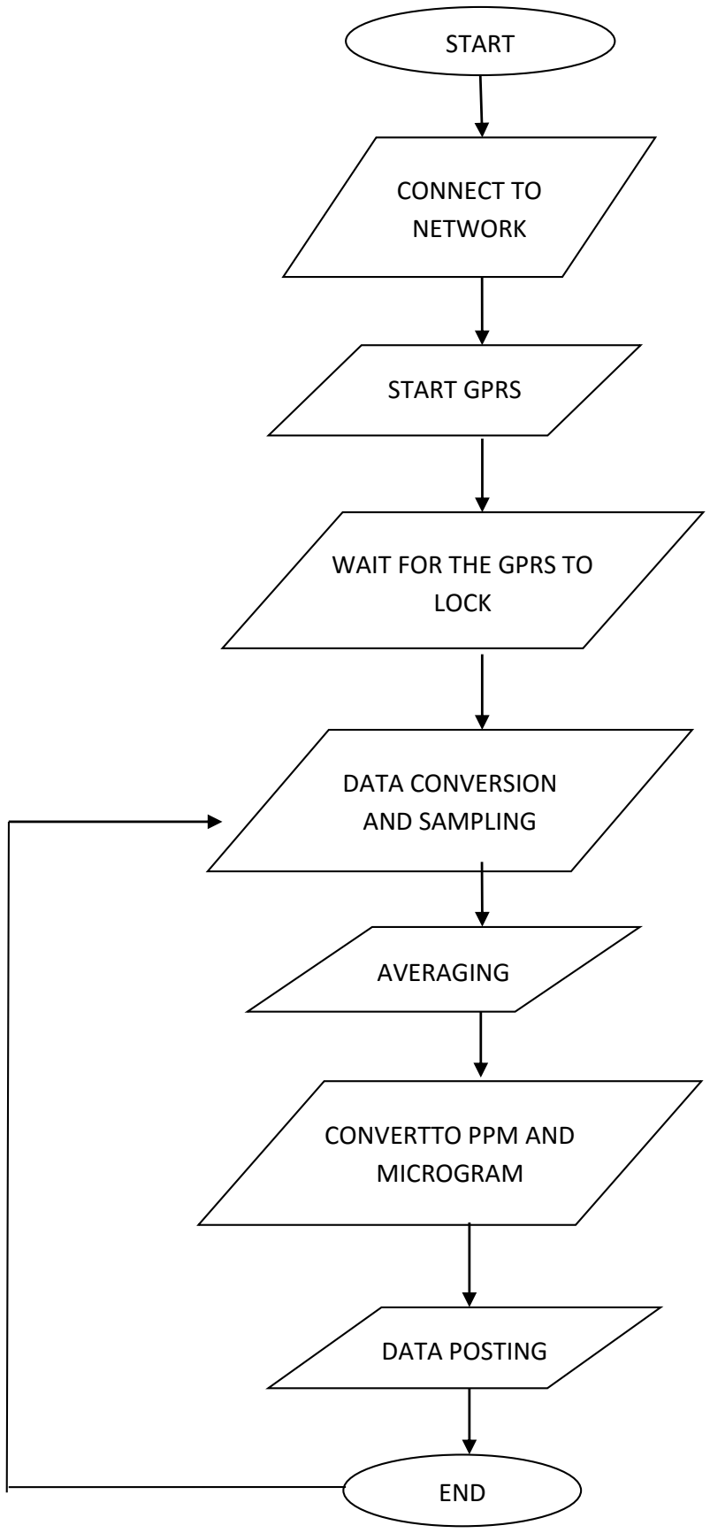
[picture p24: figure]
START; CONNECT TO NETWORK; START GPRS; WAIT FOR THE GPRS TO LOCK; DATA CONVERSION AND SAMPLING; AVERAGING; CONVERTTO PPM AND MICROGRAM; DATA POSTING; END

FIGURE 3.1 DATA ACQUISITION FLOW CHART

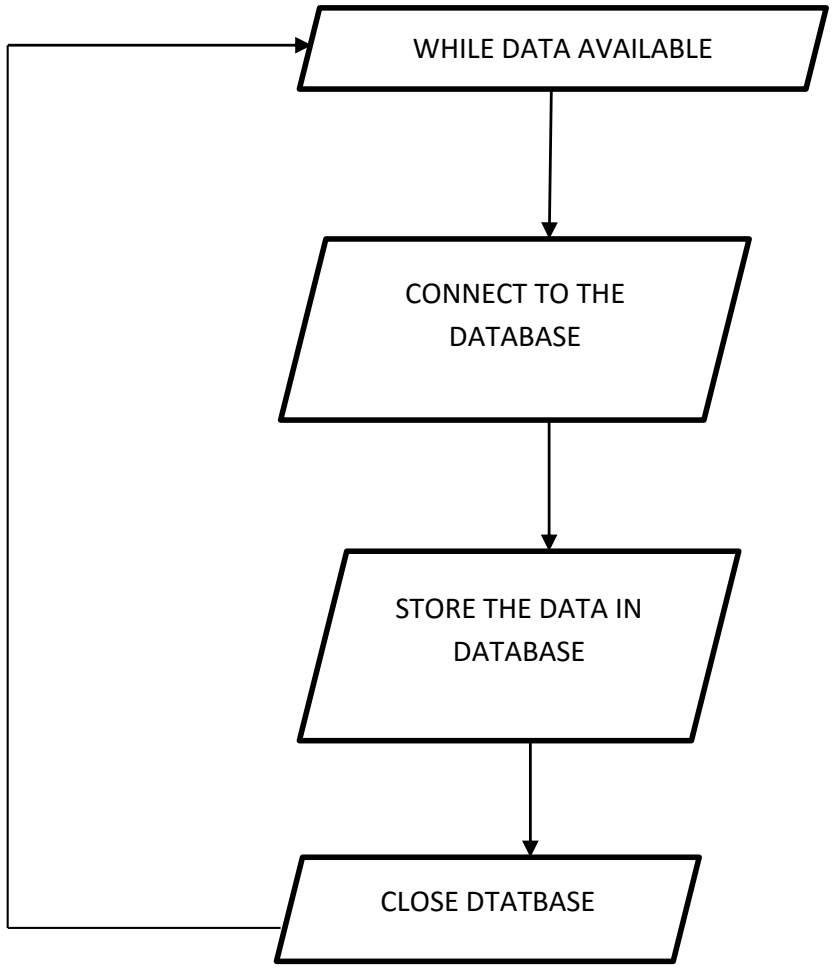
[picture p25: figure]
WHILE DATA AVAILABLE; CONNECT TO THE DATABASE; STORE THE DATA IN DATABASE; CLOSE DTATBASE

FIGURE 3.2 FLOW CHART FOR PHP HANDLING

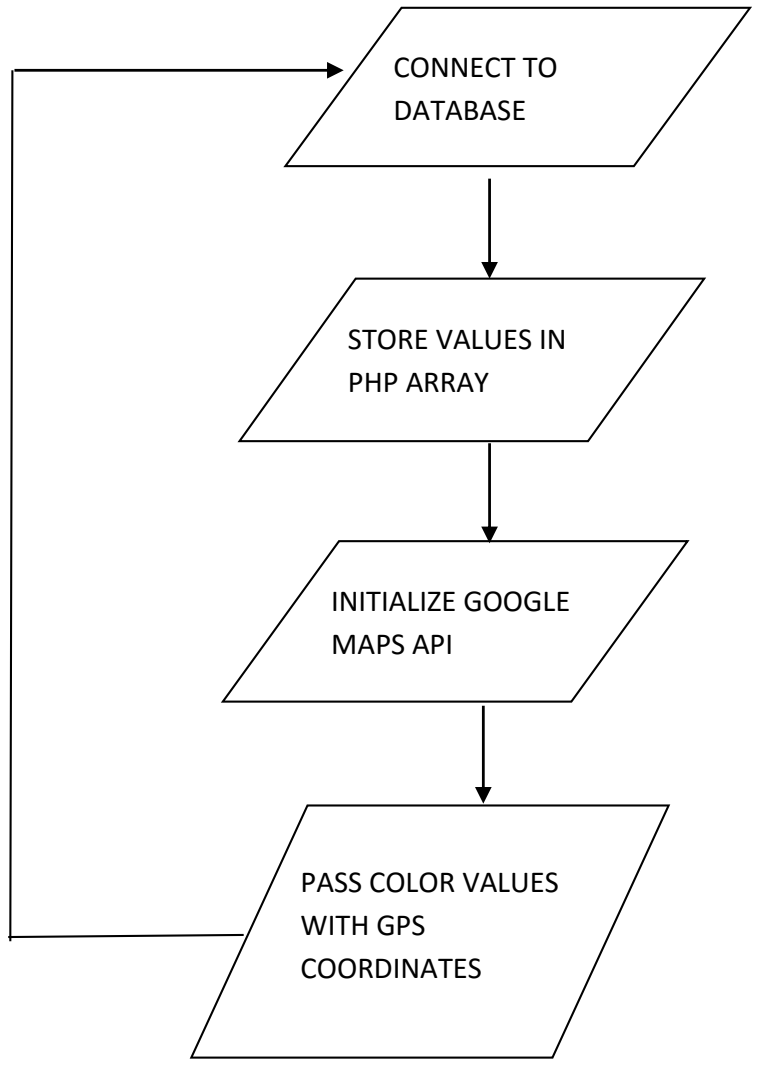
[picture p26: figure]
CONNECT TO DATABASE; STORE VALUES IN PHP ARRAY; INITIALIZE GOOGLE MAPS API; PASS COLOR VALUES WITH GPS COORDINATES

FIGURE 3.3 FLOW CHART FOR DATA RETRIEVAL

### 3.2 DATABASE MANAGEMENT

Code below shows how data is extracted and stored in data base. First

username, password and database name are stores in separate variables. Those

variables are then passed to MySQL query to get access to that database. After

successful authentication any number of queries to insert and delete data’s into

database.

Syntax for inserting database

- INSERT INTO mytable(latitude,longitude,color,size)VALUES ('$a','$b','$c','$d')

Syntax for selecting database:

- SELECT * FROM mytable

Where,

Mytable – table name

(*) – select everything

### 3.3 DATA RETRIEVAL

The processed the data and have sent the data to the server. And the

server contains a PHP handler which retrieves the data and stores it in a

database. Beside the data stored it also contains the location co-ordinates and

the colour values. The colour values are based on Indian air quality index.

AIR QUALITY INDEX | COLOUR
(0-50) GOOD | GREEN
(51-100) MODERATE | YELLOW
(101-150) UNHEALTHY FOR SENSITIVE GROUPS | BROWN
(151-200) UNHEALTHY | RED
(201-230) VERY UNHEALTHY | PURPLE
(301-500) HAZARDOUS | DARK PURPLE

Now, these data’s should be passed to google maps API, those read data’s

should be stored in a PHP array. The google API is written in JavaScript. The

PHP array should be passed to the array of JavaScript. Now, according to the

GPS location the colour values will be shown in the map. The codes for it is

shown below

### 3.4 GOOGE MAPS API

Google Maps is a desktop web mapping (https://en.wikipedia.org/wiki/Web_mapping) service developed by Google. (https://en.wikipedia.org/wiki/Google) It

offers satellite imagery, (https://en.wikipedia.org/wiki/Satellite_imagery) street maps, 360° panoramic views of streets (Street

View), (https://en.wikipedia.org/wiki/Google_Street_View) real-time traffic conditions (Google Traffic), (https://en.wikipedia.org/wiki/Google_Traffic) and route planning (https://en.wikipedia.org/wiki/Route_planner) for

traveling by foot, car, bicycle (inbeta), (https://en.wikipedia.org/wiki/Beta_test) or public transportation. (https://en.wikipedia.org/wiki/Public_transportation)

After | the | success | of | reverse-engineered | mashups | such | as

chicagocrime.org and housingmaps.com, Google launched the Google Maps

API (https://developers.google.com/maps/) in June 2005 to allow developers to integrate Google Maps into their

websites. It is a free service, and currently does not contain ads, but Google

states in their terms of use that they reserve the right to display ads in the future.

By using the Google Maps API, (https://en.wikipedia.org/wiki/Application_programming_interface) it is possible to embed Google Maps site

into an external website, on to which site specific data can be

overlaid. Although initially only a JavaScript (https://en.wikipedia.org/wiki/JavaScript) API, the Maps API was expanded

to include an API for Adobe Flash (https://en.wikipedia.org/wiki/Adobe_Flash) applications (but this has been deprecated), a

service | for | retrieving | static | map | images, | and web | services (https://en.wikipedia.org/wiki/Web_Service) for

performing geocoding, (https://en.wikipedia.org/wiki/Geocoding) generating driving directions, and obtaining elevation

profiles. Over 1,000,000 web sites use the Google Maps API, making it the

most heavily used web application development API.

The Google Maps API is free for commercial use, provided that the site

on which it is being used is publicly accessible and does not charge for access,

and is not generating more than 25 000 map accesses a day. Sites that do not

meet these requirements can purchase the Google Maps API for Business.

The success of the Google Maps API has spawned a number of

competing | alternatives, | including | the HERE | Maps (https://en.wikipedia.org/wiki/HERE_Maps) API, Bing | Maps

Platform, (https://en.wikipedia.org/wiki/Bing_Maps_Platform) Leaflet (https://en.wikipedia.org/wiki/Leaflet_(software)) and Open Layers (https://en.wikipedia.org/wiki/OpenLayers) via self-hosting. (https://en.wikipedia.org/wiki/Self-hosting) The Yahoo! Maps (https://en.wikipedia.org/wiki/Yahoo!_Maps) API is in

the process of being shut down.

In September 2011, Google announced it would discontinue a number of

its products, including Google Maps API for Flash.

### 3.5 SOFTWARE TOOLS USED

A number of design tools and development environments helped us for web

development. List of tools are as follows.

- WAMP server
- PHP designer
- Hostinger

### 3.5.1 WAMP SERVER

Wamp | Server refers | to | a | software | stack | for | the Microsoft

Windows (https://en.wikipedia.org/wiki/Microsoft_Windows) operating system, created by Romain Bourdon and consisting of

the Apache | web | server, (https://en.wikipedia.org/wiki/Apache_HTTP_Server) Open | SSL (https://en.wikipedia.org/wiki/OpenSSL) for | SSL | support, MySQL (https://en.wikipedia.org/wiki/MySQL) database

and PHP (https://en.wikipedia.org/wiki/PHP) programming language. It is used for testing our program by simply

using our PC as a server (i.e local hosting). Similar to LAMP in Linux operating

system.

### 3.5.2 PHP DESIGNER

PHP designer is a development tool which provides a complete

development environment for web development. It provides facilities to edit,

run and debug the code under a single window. It has an intelligent editor with

autocomplete feature which reduces our development time.

### 3.5.3 HOSTINGER

Hostinger provides free domains for students and professionals. They

provided a user friendly control panel which supports file transfer protocol,

database management and many. Two gigabytes of data for hosting our data’s

for free and two free database.

### 3.5.4 WORKING MODEL

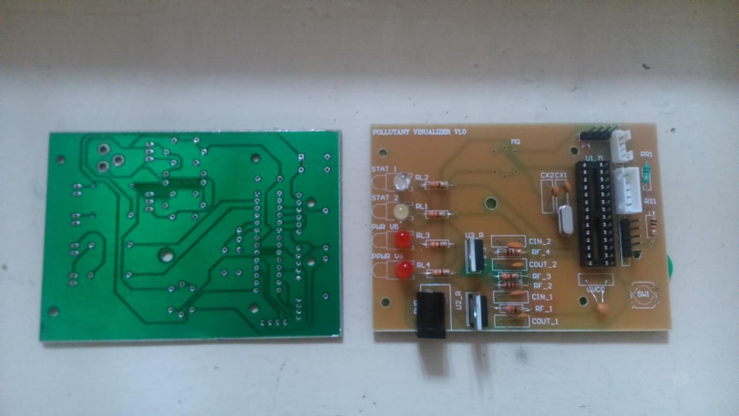
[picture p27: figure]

FIGURE 3.4 PCB AND PCB ASSEMBLY

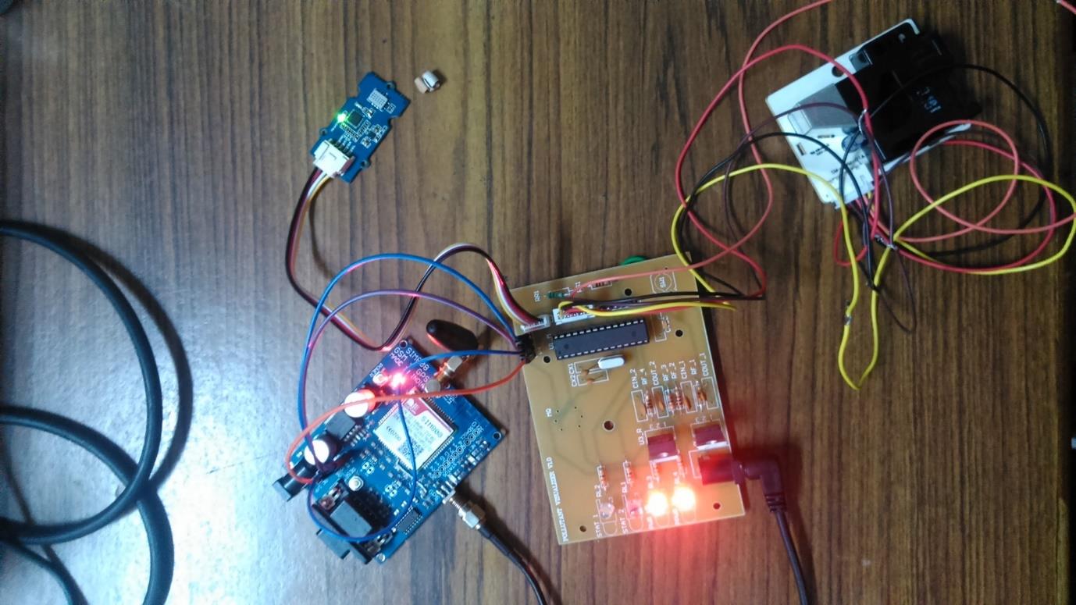
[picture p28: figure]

FIGURE 3.5 COMPLETE PROTOTYPE

RESULT

Test map of our final prototype is shown below. We have tested our

device inside our campus to get real time reading. As it is a green campus we

have very less pollution level. Colour dot is in green which is called as good

according to Air Quality Index, India. Each value on map is based on the

pollutant that are measured. In future some information’s about colour and

check boxes will be added to sort out what we are looking for.

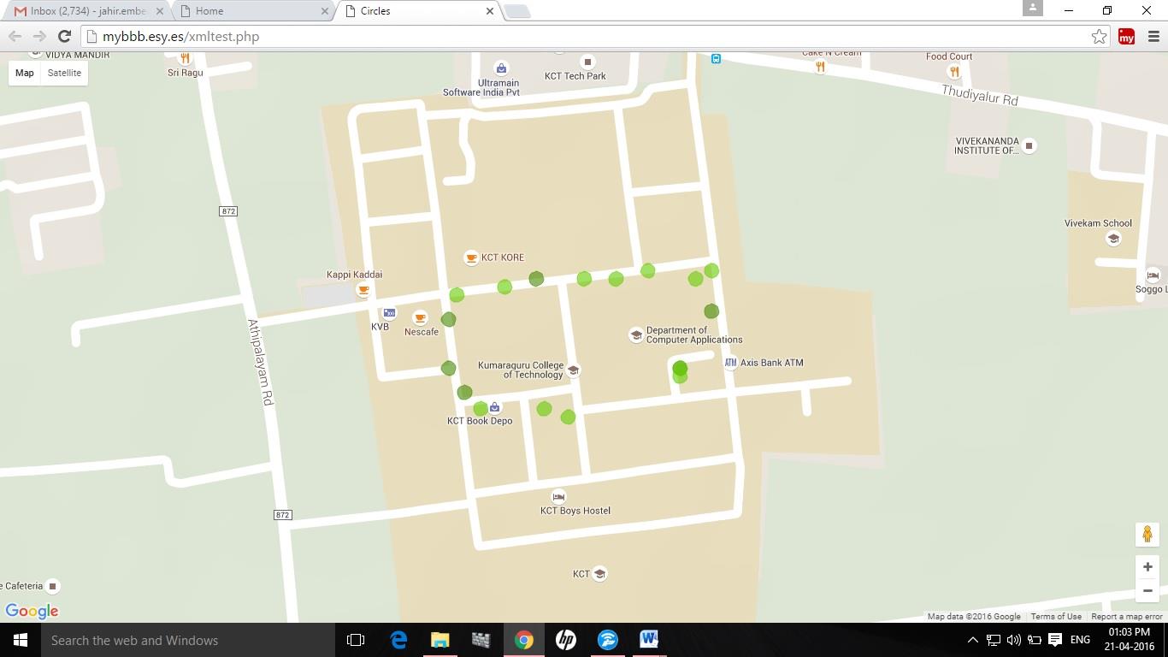
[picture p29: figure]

FIGURE 3.6 ENVIRONMENT TEST

CHAPTER 4

CONCLUSION

This system creates an open community for people to get self-awareness

about their surrounding environment. To increase affordability to reach

everyone and reduced size to be fit inside a pocket for portability the design has

been optimized many times. We have taken a step to create a clean and eco-

friendly environment for our future generation. By implementing this in real

time we can have personalized health awareness for an individual and they can

take part into our open community map so that everyone gets benefited.

REFERENCES

1. http://aqicn.org/map/india/
2. http://gasp-pgh.org/
3. http://www.figarosensor.com/technicalinfo/principle/electrochemical-

type.html (http://www.figarosensor.com/technicalinfo/principle/electrochemical-type.html)

4. http://www.figarosensor.com/technicalinfo/principle/catalytic-type.html
5. https://sgx.cdistore.com/
6. http://www.ti.com/tool/TIDA-00378
7. http://www.analog.com/media/en/referencedesigndocumentation/referenc

e-designs/CN0272.pdf (http://www.analog.com/media/en/referencedesigndocumentation/reference-designs/CN0272.pdf)

8. http://www.ncbi.nlm.nih.gov/pmc/articles/PMC3264469/
9. http://forum.arduino.cc/

10.http://electronicdesign.com/iot/understanding-protocols-behind-internet-

things (http://electronicdesign.com/iot/understanding-protocols-behind-internet-things)

11.http://www.simcom.ee/modules/gsm-gprs-gnss/sim808/

12.http://www.ti.com/lsds/ti/analog/webench/overview.page?DCMP=sva_w

ebench&HQS=webench-btechday (http://www.ti.com/lsds/ti/analog/webench/overview.page?DCMP=sva_webench&HQS=webench-btechday)

13.http://www.ti.com/lsds/ti/analog/webench/power.page

14.http://www.seeedstudio.com/wish/breakout-board-for-mics-6814-

multigas-sensor-p2621 (http://www.seeedstudio.com/wish/breakout-board-for-mics-6814-multigas-sensor-p2621)

15.http://playground.arduino.cc/Main/MQGasSensors

16.http://www.daycounter.com/Calculators/Voltage-Regulator-Resistor-

Divider-Calculator.phtml (http://www.daycounter.com/Calculators/Voltage-Regulator-Resistor-Divider-Calculator.phtml)

17.http://searchdatamanagement.techtarget.com/definition/data-analytics

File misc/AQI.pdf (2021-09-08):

### Пенги

индекс квалитета ваздуха (AQI)


0 - 50 | Добар
51 - 100 | Умерено добар | Не препоручује се дужи боравак на отвореном осетљивом делу популације (деца, стари, хронични болесници)
101 - 150 | Нездрав за осетљиву популацију (деца,стари, хронични болесници)

Особе са срчаним и плућним обољењима, старије особе и деца треба да ограниче боравак на отвореном (јутарњи и вечерњи сати се не препоручују).

151 - 200 | Нездрав | Особе са срчаним и плућним обољењима, старије особе и деца треба да избегавају боравак напољу и продужену физичку активност. Пожељно је смањење продужене и напорне физичке активности здравог дела популације.
201 - 300 | Врло нездрав | Особе са срчаним и плућним обољењима, старије особе и деца треба да избегавају било какву активност напољу. Остали би требали да избегавају продужене и тешке напоре.Не препоручује се проветравање станова у јутарњим и вечерњим сатима.
301 - | Опасно | Особе са срчаним и плућним обољењима, старије особе и деца треба да скрате боравак напољу и ако је могуће да остану у кући и смање активности. Хронични болесници морају узимати редовну терапију а у случају погоршања здравственог стања обавезно се обратити лекару. Остали треба да избегавају активности напољу. Не препоручује се проветравање станова у јутарњим и вечерњим сатима.

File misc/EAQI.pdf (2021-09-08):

Пенги

европски индекс квалитета ваздуха (EAQI)


PM2.5 0 - 10
PM10 0 - 20

Добар

PM2.5 10 - 20
PM10 20 - 40

У реду

PM2.5 20 - 25
PM10 40 - 50

Умерен

PM2.5 25 - 50
PM10 50 - 100

Лош

PM2.5 50 - 75
PM10 100 – 150

Веома лош

PM2.5 75 - 800
PM10 150 - 1200

Ектремно
лош

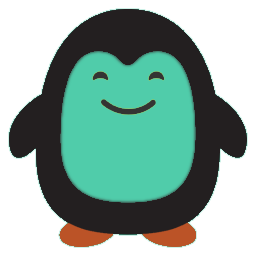
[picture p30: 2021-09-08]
media/QI emojis/EAQI emoji - Fair.png

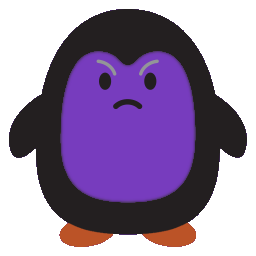
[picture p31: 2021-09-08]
media/QI emojis/AQI emoji - Very unhealthy.png

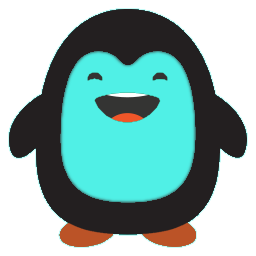
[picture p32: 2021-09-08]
media/QI emojis/EAQI emoji - Good.png

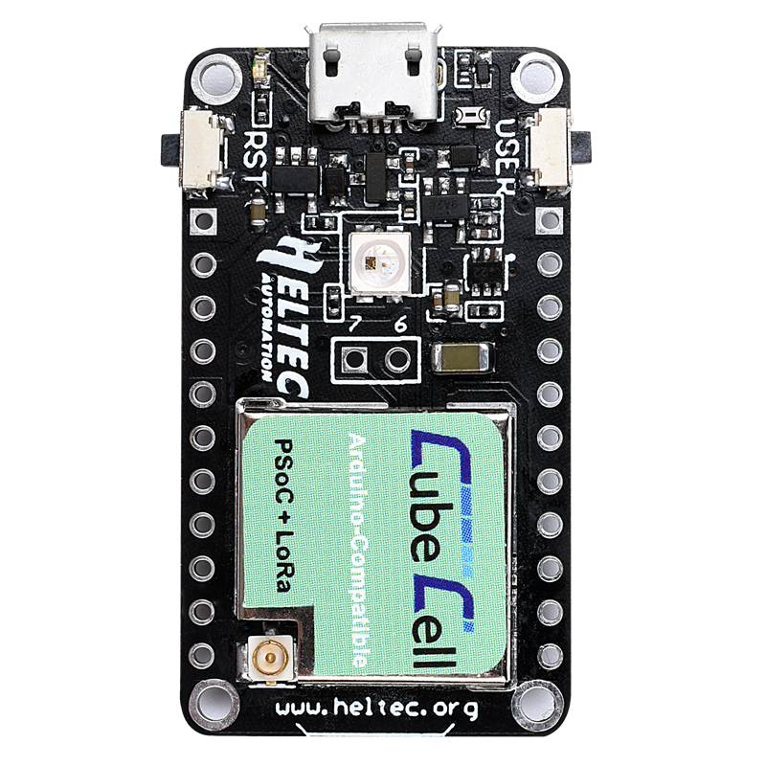
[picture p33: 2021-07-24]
firmware/docs/CubeCell HTCC-AB01.png

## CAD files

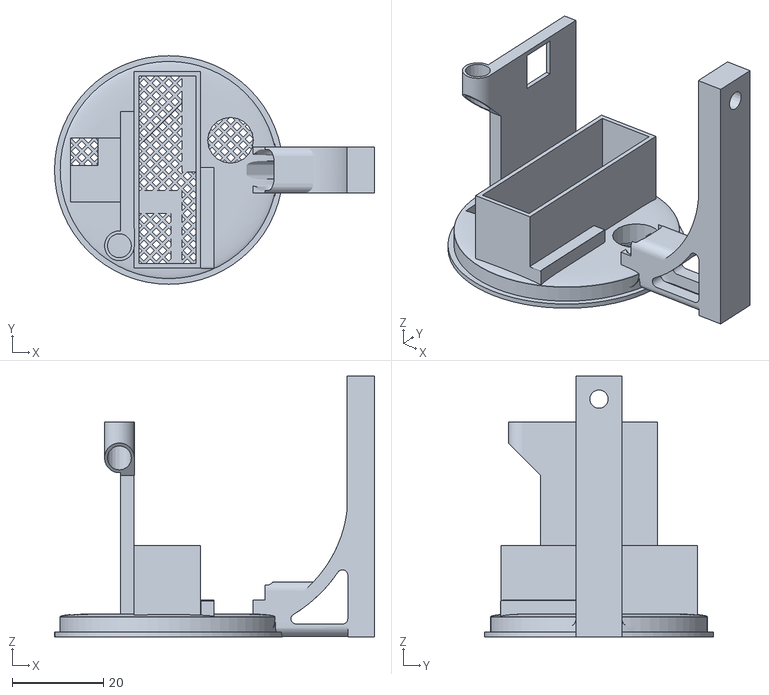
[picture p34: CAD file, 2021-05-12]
enclosure/Pengy - mount.stl
70.0 x 50.0 x 57.0

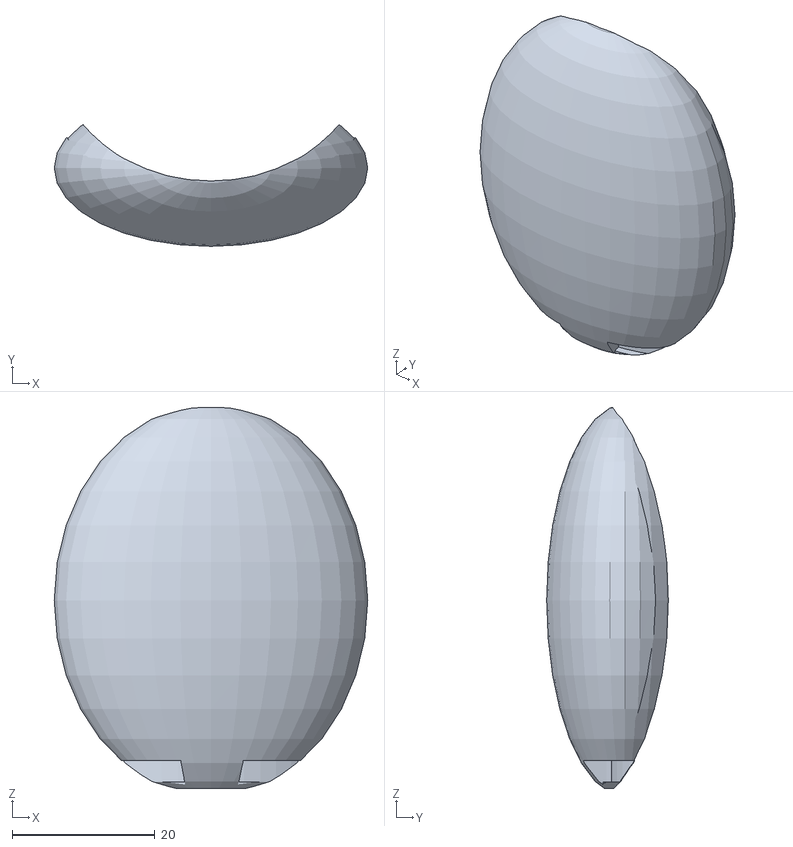
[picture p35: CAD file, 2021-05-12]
enclosure/Pengy - stomach.stl
43.9 x 17.1 x 53.4

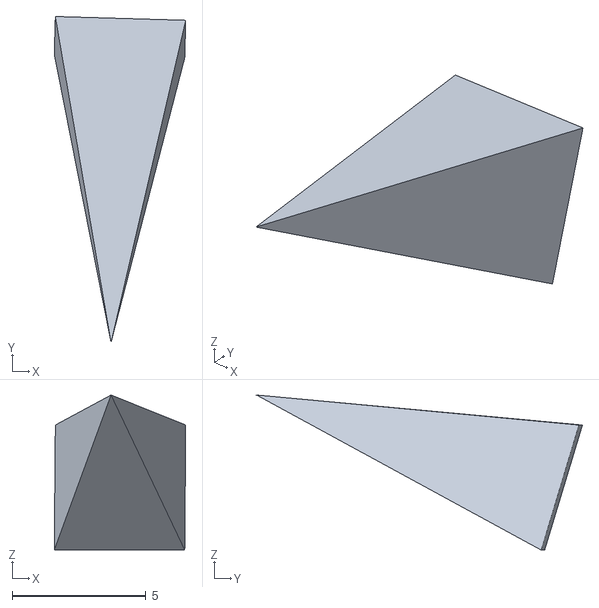
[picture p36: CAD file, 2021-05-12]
enclosure/Pengy - nose.stl
4.92 x 12.2 x 5.79

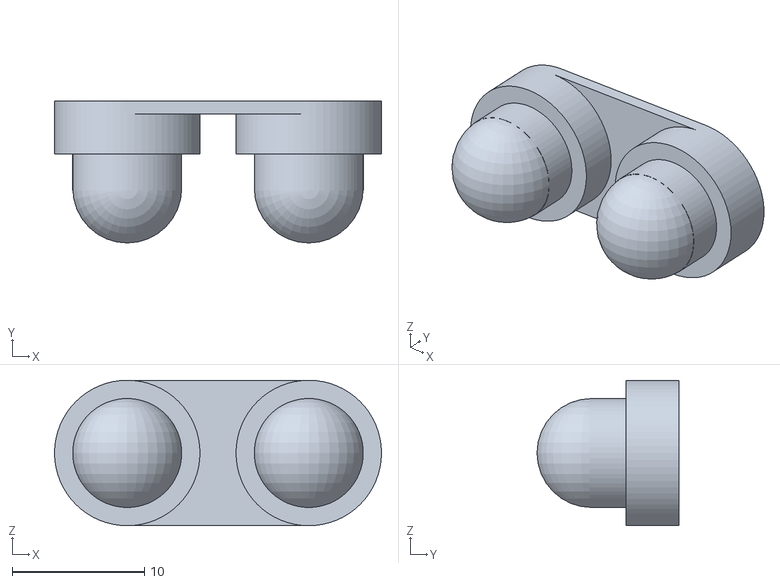
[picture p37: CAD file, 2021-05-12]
enclosure/Pengy - eyes.stl
24.7 x 10.7 x 11.0

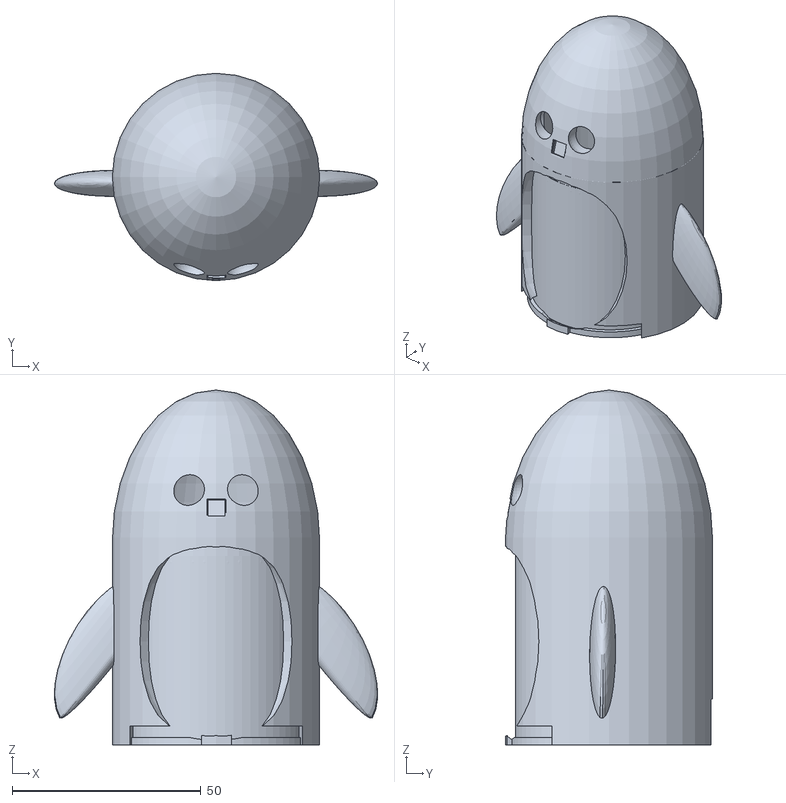
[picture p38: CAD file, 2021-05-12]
enclosure/Pengy - body.stl
85.6 x 54.9 x 94.0

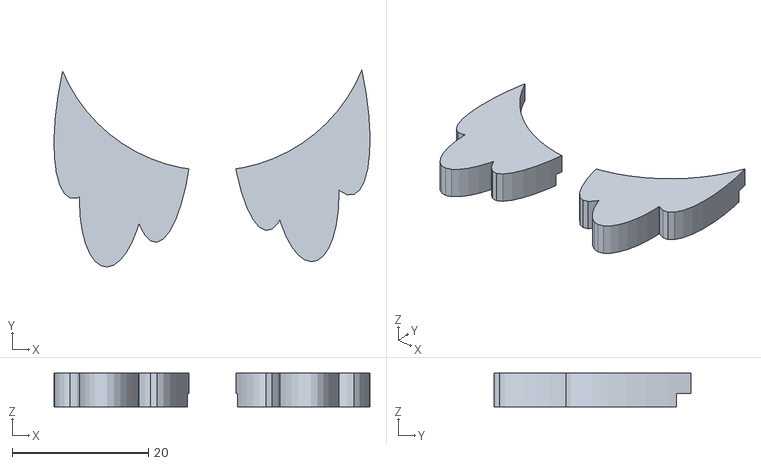
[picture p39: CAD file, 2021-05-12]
enclosure/Pengy - feet.stl
46.5 x 29.0 x 4.99

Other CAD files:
enclosure/Pengy - mount (centered antenna).stl

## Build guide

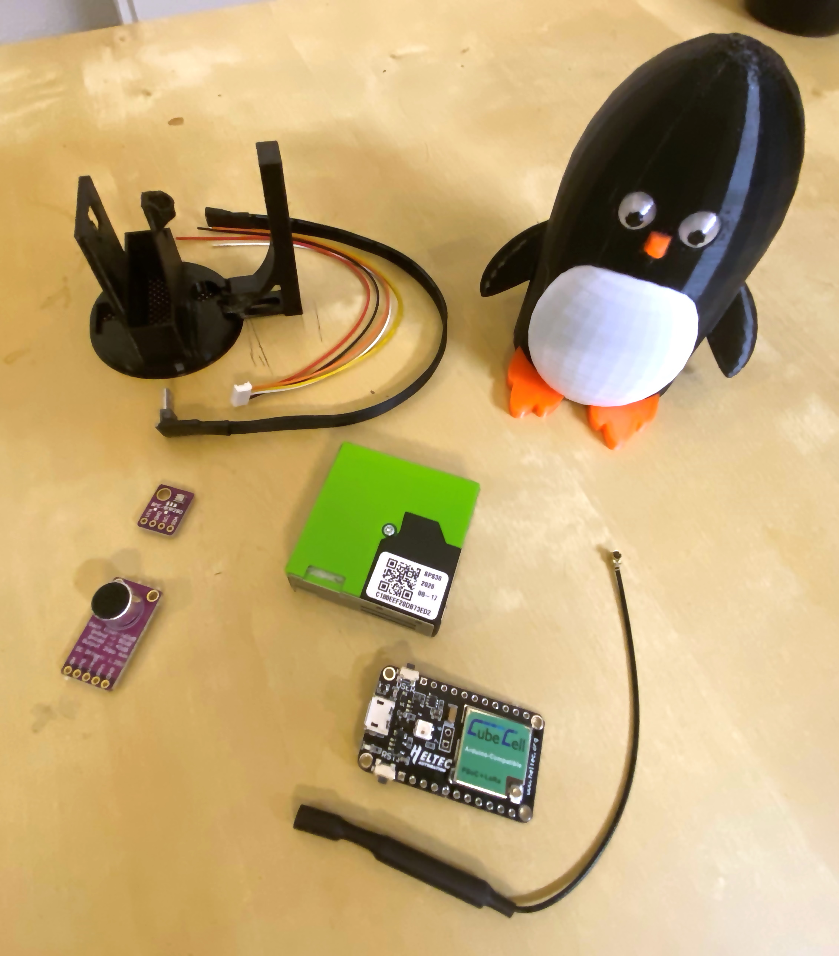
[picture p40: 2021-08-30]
media/Construction Kit v2.0.jpg

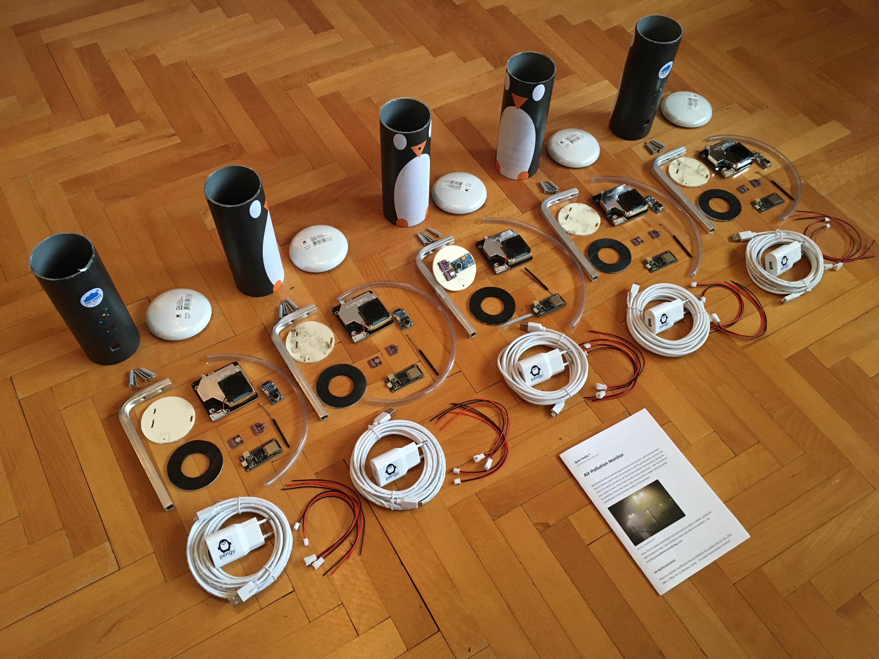
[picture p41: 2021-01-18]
media/Construction Kit v1.5.jpg

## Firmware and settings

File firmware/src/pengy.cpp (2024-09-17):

/*
  Pengy v2.0 - Air Quality Parameters acquisition

  This firmware acquires:
     - PM1.0, PM2.5 and PM10 concetration from Sensirion SPS30 sensor
     - temperature, humidity and preassure from BME680 sensor
     - sound level from MAX9814 electret microphone

  then accumulates, agregates data and sends it every hour using LoRaWAN 
  via The Things Network to Thingy.IO system.

  Copyright (c) 2021 Dusan Stojkovic
*/

#include "Arduino.h"
#include "Wire.h"

#include "LoRaWanMinimal_APP.h"

#include <Streaming.h>

#include <SPS30.h>

double pm1Cummulative=0, pm25Cummulative=0, pm10Cummulative=0;
int countAQCummulative=0;

float pm1, pm25, pm10;
SPS30 sps30;

#include <Adafruit_Sensor.h>
#include "Adafruit_BME280.h"
Adafruit_BME280 bme;

long temperatureCummulative=0;
long humidityCummulative=0;
long pressureCummulative = 0;
int countTHPCummulative=0;

float temperature;
float humidity;
float pressure;

double soundValueCummulative=0;
int countSoundValueCummulative = 0;

float noise = 0;

#include "CubeCell_NeoPixel.h"
CubeCell_NeoPixel eyes(1, RGB, NEO_GRB + NEO_KHZ800);

#define DEBUG true
#define LOG if(DEBUG)Serial

// ABP
static const uint8_t NWKSKEY[16] = NWK_S_KEY;
static const uint8_t APPSKEY[16] = APP_S_KEY;
static const uint32_t DEVADDR = DEV_ADDR;

// OTAA
static uint8_t devEui[] = DEV_EUI;
static uint8_t appEui[] = APP_EUI;
static uint8_t appKey[] = APP_KEY;

uint16_t userChannelsMask[6]={ 0x00FF,0x0000,0x0000,0x0000,0x0000,0x0000 };

unsigned int loops = 0;

bool send = false;
uint8_t data[14];

// LED lights and effects

void lightInit()
{
    pinMode(Vext,OUTPUT);
    digitalWrite(Vext,LOW);
    eyes.begin(); eyes.clear(); eyes.show();
}

static TimerEvent_t lightEvent;
volatile uint32_t lightTicks;
enum lightEffect_t { RANDOM, RAINBOW, PULSE_RGB} ;

static lightEffect_t lightEffect;

void lightTick()
{
    switch (lightEffect)
    {
        case RANDOM:
            eyes.setPixelColor(0, eyes.Color(random(255), random(255), random(255)));
            break;
        case RAINBOW:
            eyes.setPixelColor(0, eyes.Color(eyes.sine8((lightTicks-85) % 256), eyes.sine8(lightTicks % 256), eyes.sine8((lightTicks+85) % 256)));
            break;
        case PULSE_RGB:
            break;
    }
    eyes.show();
    
    lightTicks = (lightTicks + 1) ;

    TimerSetValue(&lightEvent, 10);
    TimerStart(&lightEvent);
}

void lightEffectStart(lightEffect_t effect)
{
    eyes.begin();
    lightTicks = 0;
    lightEffect = effect;
    lightTick();
}

void lightEffectStop()
{
    TimerStop(&lightEvent);
    eyes.clear(); eyes.show();
}

void lightSetupBegin()
{
    eyes.begin(); 
    for(int c = 0; c < 3; c++ ) {
        for(int k = 0; k < 256; k++) {
            switch(c) {
                case 0: eyes.setPixelColor(0, eyes.Color(k,0,0));  break;
                case 1: eyes.setPixelColor(0, eyes.Color(0,k,0));  break;
                case 2: eyes.setPixelColor(0, eyes.Color(0,0,k));  break;
            }
            eyes.show(); 
            delay(1);
        }
        for(int k = 255; k >= 0; k--) {
            switch(c) {
                case 0: eyes.setPixelColor(0, eyes.Color(k,0,0));  break;
                case 1: eyes.setPixelColor(0, eyes.Color(0,k,0));  break;
                case 2: eyes.setPixelColor(0, eyes.Color(0,0,k));  break;
            }
            eyes.show(); 
            delay(1);
        }
    }
}

void lightSetupStop()
{
    eyes.clear(); eyes.show();    
}

// Acquisition

void acquireNoise()
{
    LOG << endl << F("Noise >>>") << endl;

    lightEffectStart(RAINBOW);

    unsigned long start_ts = millis();
    while (millis() - start_ts < 5000)
    {
        double soundValMin=3.4028235E+38, soundValSubMin=3.4028235E+38, soundValMax=-3.4028235E+38, soundValSubMax= -3.4028235E+38;

        unsigned long sound_ts= millis();
        while (millis() - sound_ts < 125) // 125ms
        {
            int soundVal = 0; for (int i=0; i<3; i++) soundVal += analogRead(ADC); soundVal/=4;

            if (soundVal < soundValMin) 
            {
                soundValSubMin = soundValMin;
                soundValMin = soundVal;
            }
            else if (soundVal < soundValSubMin)
                soundValSubMin = soundVal;
            
            if (soundVal > soundValMax) 
            {
                soundValSubMax = soundValMax;
                soundValMax = soundVal;
            }
            else if (soundVal > soundValSubMax)
                soundValSubMax = soundVal;
        }
        
        soundValMax = soundValSubMax;
        soundValMin = soundValSubMin;

        soundValueCummulative += soundValMax - soundValMin; // accumulate envelope
        countSoundValueCummulative++;
    }

    LOG << " span Cum = " << soundValueCummulative << "   span Cnt " << countSoundValueCummulative << endl;
    lightEffectStop();

    LOG << F("<<<") << endl << endl;;    

    noise = soundValueCummulative / countSoundValueCummulative;
    noise = CAL_NOISE_1 * log(noise) + CAL_NOISE_0;    
}

void acquireTHP()
{
    LOG << endl << F("THP >>>") << endl;

    lightEffectStart(RAINBOW);

    float temperatureMin=3.4028235E+38, temperatureMax=-3.4028235E+38;
    float humidityMin=3.4028235E+38, humidityMax=-3.4028235E+38;
    float pressureMin=3.4028235E+38, pressureMax=-3.4028235E+38;
    int thpCount = 0;
    
    for (int l=0; l<7; l++)
    {
        float temperature = bme.readTemperature();         // °C
        float humidity    = bme.readHumidity();            // %RH
        float pressure    = bme.readPressure() * 0.01f;    // hPa
        float altitude    = bme.readAltitude(1013.25);     // m

        if (!isnanf(temperature) && !isnanf(humidity) && !isnanf(pressure))
        {
            LOG << F(" (") << (l+1) << F(")   t=") << temperature << F("°C   H=") << humidity << F("%RH   p=") << pressure << F(" hPa   MASL=") << altitude << F(" m") << endl;

            temperatureCummulative += temperature;
            if (temperature < temperatureMin) temperatureMin = temperature;
            if (temperature > temperatureMax) temperatureMax = temperature;                

            humidityCummulative += humidity;
            if (humidity < humidityMin) humidityMin = humidity;
            if (humidity > humidityMax) humidityMax = humidity;                

            pressureCummulative += pressure;
            if (pressure < pressureMin) pressureMin = pressure;
            if (pressure > pressureMax) pressureMax = pressure;   

            thpCount++;
            countTHPCummulative++;
        }
        else
        {
            LOG << F(" (") << (l+1) << F(")  X") << endl;
        }
        delay(1000);
    }
    LOG << "t m " << temperatureMin << " M " << temperatureMax << endl;
    LOG << "H m " << humidityMin << " M " << humidityMax << endl;
    LOG << "p m " << pressureMin << " M " << pressureMax << endl;

    if (thpCount > 2)
    {
        temperatureCummulative = temperatureCummulative - temperatureMax - temperatureMin;
        humidityCummulative = humidityCummulative - humidityMax - humidityMin;
        pressureCummulative = pressureCummulative - pressureMax - pressureMin;
        countTHPCummulative = countTHPCummulative - 2;
    }
    
    lightEffectStop();

    LOG << F("<<<") << endl << endl;
    
    temperature = 1.0 * temperatureCummulative / countTHPCummulative;
    humidity = 1.0 * humidityCummulative / countTHPCummulative;
    pressure = 1.0 * pressureCummulative / countTHPCummulative;

    temperature = CAL_TEMPERATURE_1 * temperature + CAL_TEMPERATURE_0;
    humidity    = CAL_HUMIDITY_1    * humidity    + CAL_HUMIDITY_0;
    pressure    = CAL_PRESSURE_1    * pressure    + CAL_PRESSURE_0;    
}

void acquirePM(bool clean)
{
    LOG << endl << F("PM >>>") << endl;
    
    lightEffectStart(RAINBOW);

    bool began = sps30.beginMeasuring();
    LOG << (began ? F("+"):F("-")) << endl;
    
    if (clean)
    {
        LOG << F("Performin manual cleaning") << endl;
        sps30.sendCommand(COMMAND_START_FAN_CLEANING);
    }

    delay(30000);

    float pm1Min=3.4028235E+38, pm1Max=-3.4028235E+38;
    float pm25Min=3.4028235E+38, pm25Max=-3.4028235E+38;
    float pm10Min=3.4028235E+38, pm10Max=-3.4028235E+38;
    int pmCount = 0;

    for (int l=0; l<7; l++)
    {
        if (sps30.readMeasurement())
        {
            LOG <<F(" (") << (l+1) << F(")   PM1.0=") << sps30.massPM1 << F("µg/m³  PM2.5=") << sps30.massPM25 << F("µg/m³  PM4.0=") << sps30.massPM4 << F("µg/m³  PM10=") << sps30.massPM10 << F("µg/m³  size=") << sps30.typPartSize << F("µm") << endl;

            pm1Cummulative += sps30.massPM1;
            if (sps30.massPM1 < pm1Min) pm1Min = sps30.massPM1;
            if (sps30.massPM1 > pm1Max) pm1Max = sps30.massPM1;

            pm25Cummulative += sps30.massPM25;
            if (sps30.massPM25 < pm25Min) pm25Min = sps30.massPM25;
            if (sps30.massPM25 > pm25Max) pm25Max = sps30.massPM25;

            pm10Cummulative += sps30.massPM10;
            if (sps30.massPM10 < pm10Min) pm10Min = sps30.massPM10;
            if (sps30.massPM10 > pm10Max) pm10Max = sps30.massPM10;                

            pmCount++;
            countAQCummulative++;
        }
        /*
        else 
        {
          LOG << F(" (") << (l+1) << F(") X   ") << pm.statusToString() << endl;
        }
        */
        delay(1000);
    }            
    
    //LOG << "cnt " << pmCount << endl;
    //LOG << "fpm m " << fpmMin << " M " << fpmMax << endl;
    //LOG << "pm10 m " << pm10Min << " M " << pm10Max << endl;

    if (pmCount > 2)
    {
        pm1Cummulative = pm1Cummulative - pm1Max - pm1Min;
        pm25Cummulative = pm25Cummulative - pm25Max - pm25Min;
        pm10Cummulative = pm10Cummulative - pm10Max - pm10Min;
        countAQCummulative = countAQCummulative - 2;
    }
    
    bool stopped = sps30.stopMeasuring();
    LOG << (stopped ? F("+"):F("-")) << endl;
    
    lightEffectStop();

    LOG << F("<<<") << endl << endl;
    
    pm1 = 1.0 * pm1Cummulative / countAQCummulative;
    pm25 = 1.0 * pm25Cummulative / countAQCummulative;
    pm10 = 1.0 * pm10Cummulative / countAQCummulative;

    pm10 = CAL_PM10_1 * pm10 + CAL_PM10_0;
    pm1 = CAL_PM1_1 * pm1 + CAL_PM1_0;
    pm25 = CAL_PM25_1 * pm25 + CAL_PM25_0;    
}

void acquireReset()
{
    countSoundValueCummulative = 0;
    soundValueCummulative = 0;

    countTHPCummulative = 0;
    temperatureCummulative = 0;
    humidityCummulative = 0;
    pressureCummulative = 0;

    countAQCummulative=0;
    pm1Cummulative=0;
    pm25Cummulative=0;
    pm10Cummulative=0;
}

/*
void downLinkDataHandle(McpsIndication_t *mcpsIndication)
{
  Serial.printf("Received downlink: %s, RXSIZE %d, PORT %d, DATA: ",mcpsIndication->RxSlot?"RXWIN2":"RXWIN1",mcpsIndication->BufferSize,mcpsIndication->Port);
  for(uint8_t i=0;i<mcpsIndication->BufferSize;i++) {
    Serial.printf("%02X",mcpsIndication->Buffer[i]);
  }
  Serial.println();
}
*/

// Setup & Loop
void setup()
{
    while (!Serial && millis() < 10000);
    Serial.begin(115200);
    Wire.begin();

    delay(10);
    Serial << endl << endl  << F(_NAME_) << " - " << F(__DATE__) << " " << F(__TIME__) << endl << "#" << endl << endl;

    // LED init
    lightInit();
    TimerInit(&lightEvent, lightTick);
    lightSetupBegin();

    // air quiality sensor
    Serial << F("Initializing SPS30 sensor ... ");
    bool initAQ = sps30.begin(Wire); 
    Serial << (initAQ ? F("OK") : F("NOK")) << endl;;

    // temperature, humidity, preassure
    Serial << F("Initializing BME280 sensor ... ");
    bool initTHP = bme.begin(0x76, &Wire);
    Serial << (initTHP ? F("OK") : F("NOK")) << endl;;

    // LoRaWAN
    Serial << F("Initializing LoRaWAN ... ");
    boardInitMcu();
    LoRaWAN.begin(LORAWAN_CLASS, ACTIVE_REGION);
    LoRaWAN.setAdaptiveDR(true);
    Serial << F("OK") << endl;

    // ABP
    /*
    Serial << F("  joining (ABP)... ");
    bool joined = LoRaWAN.joinABP((uint8_t*)NWKSKEY, (uint8_t*)APPSKEY, DEVADDR);
    
    // workaround to set NetId
    MibRequestConfirm_t mibReq;
	mibReq.Type = MIB_NET_ID;
	mibReq.Param.NetID = 0x13;
	LoRaMacMibSetRequestConfirm(&mibReq);
    
    Serial << (joined ? F("OK") : F("NOK")) << endl;
	*/

    // OTAA
    bool joined = false;
    while (!joined) {
        Serial << F("  joining (OTAA)... ");
        joined = LoRaWAN.joinOTAA(appEui, appKey, devEui);
        Serial << (joined ? F("OK") : F("Failed - repeating in 1 min")) << endl;
        if (!joined) delay(60000);
    }

    // LED out
    lightInit();
    lightSetupStop();

    Serial << "#" << endl << endl;
}

void loop()
{
    unsigned long loop_ts = millis();

    Serial << endl << F("[") << loop_ts << F(" m / ") << loops <<  F(" l] ") << endl;

    if (loops % 1 == 0) // every minute - sample noise
    {
        acquireNoise();
        Serial << F("NOISE ") << F("v=") << noise << F("dBA") << endl;
    }

    if (loops % 5 == 0) // every 5 minutes - sample THP
    {
        acquireTHP();
        Serial << F("THP ") << F("t=") << temperature << F("°C - H=") << humidity<< F("%RH - p=") << pressure << F(" hPa") << endl;        
    }

    if (loops % 10 == 0) // every 10 minutes - sample particulates
    {
        bool cleaning = loops % 10080 == 0; // clean once a week
        acquirePM(cleaning);
        Serial << F("PM ") << F(" 1.0=") << pm1 << F("µg/m³  2.5=") << pm25 << F("µg/m³  4.0=") << 0 << F("µg/m³  10=") << pm10 << F("µg/m³") << endl;        
    }

    if (loops % 20 == 2) // every 20 minutes - send
    {
        uint16_t datum;

        // Humidity
        datum = humidity * 10;
        data[0] = ( datum >> 8 ) & 0xFF; data[1] = datum & 0xFF;
        // Temperature
        datum = temperature * 10;
        data[2] = ( datum >> 8 ) & 0xFF; data[3] = datum & 0xFF;
        // Pressure
        datum = pressure;
        data[4] = ( datum >> 8 ) & 0xFF; data[5] = datum & 0xFF;

        // PM 1.0
        datum = pm1 * 10;
        data[6] = ( datum >> 8 ) & 0xFF; data[7] = datum & 0xFF;
        // PM 2.5
        datum = pm25 * 10;
        data[8] = ( datum >> 8 ) & 0xFF; data[9] = datum & 0xFF;
        // PM 10
        datum = pm10 * 10;
        data[10] = ( datum >> 8 ) & 0xFF; data[11] = datum & 0xFF;

        // Noise
        datum = noise * 100;
        data[12] = ( datum >> 8 ) & 0xFF; data[13] = datum & 0xFF;
        
        send = true;
    }

    if (send)
    {
        // LED on
        lightEffectStart(RANDOM);

        // transmit
        Serial << F("Sending[") << millis() << F("]-");
        bool sent = LoRaWAN.send(sizeof(data), data, 3, false);
        Serial << (sent ? F("OK") : F("NOK")) << endl; 
        
        if (sent)
        {
            acquireReset();
            send=false;
        }

        // LED off
        delay(500);
        lightEffectStop();
    }

    LOG << F("[") << (0.001*(millis()-loop_ts)) << F(" s]") << endl << endl << endl << endl;  
    
    // Color to match EAQI (https://coolors.co/50f0e6-50ccaa-f0e641-ff5050-960032-7d2181)
    eyes.clear();
    if (pm25 >= 75 && pm25 < 800 || pm10 >= 100 && pm10 < 1200) { eyes.setPixelColor(0, eyes.Color(125,33,129)); } else // Extremely poor
    if (pm25 >= 50 && pm25 <  75 || pm10 >= 100 && pm10 <  150) { eyes.setPixelColor(0, eyes.Color(150,0,50)); } else // Very poor
    if (pm25 >= 25 && pm25 <  50 || pm10 >=  50 && pm10 <  100) { eyes.setPixelColor(0, eyes.Color(255,80,80)); } else // Poor
    if (pm25 >= 20 && pm25 <  25 || pm10 >=  40 && pm10 <   50) { eyes.setPixelColor(0, eyes.Color(240,230,65)); } else // Moderate
    if (pm25 >= 10 && pm25 <  20 || pm10 >=  20 && pm10 <   40) { eyes.setPixelColor(0, eyes.Color(80,204,170)); } else // Fair
    if (pm25 >=  0 && pm25 <  10 || pm10 >=   0 && pm10 <   20) { eyes.setPixelColor(0, eyes.Color(80,240,230)); } // Good
    eyes.show();
    //

    while (millis() - loop_ts < 60000L) { delay(1000); } // sleep until full minute
    loops++;    

    //if (loops == 3) loops = 0; // DEBUG ONLY

    eyes.setPixelColor(0, eyes.Color(255,255,255)); eyes.show(); delay(250); eyes.clear(); eyes.show();
}

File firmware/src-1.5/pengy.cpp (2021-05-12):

/*
  Pengy v1.5 - Air Quality Parameters acquisition

  This firmware acquires:
     - PM2.5 and PM10 concetration from SDS011 sensor
	 - [external pengy-acqusition.cpp] temperature, humidity and preassure from BME680 sensor
     - [external pengy-acqusition.cpp] CO, NH3 and NO2 from MiCS-6814 sensor
     - [external pengy-acqusition.cpp] sound level from LM386 enabled electret microphone (https://www.waveshare.com/sound-sensor.htm)
     
  then accumulates, agregates data and sends it every hour using LoRaWAN 
  via The Things Network to Thingy.IO system.

  Copyright (c) 2021 Dusan Stojkovic
*/

#include <Wire.h>
#include <SPI.h>
#include <lmic.h>
#include <hal/hal.h>
#include <Streaming.h>

#include <SdsDustSensor.h>
SoftwareSerial sdss(0,1);
SdsDustSensor sds(Serial1);

double fpmCummulative=0;
double rpmCummulative=0;
int countAQCummulative=0;

float fpm;
float rpm;

float noise;

float concetrationCO;
float concetrationNH3;
float concetrationNO2;

float temperature;
float humidity;
float pressure;

#include <pengy-acqusition.hpp>

//
#define DEBUG true
#define LOG if(DEBUG)Serial

#ifdef _NAME_
static const uint8_t NWKSKEY[16] = NWK_S_KEY;
static const uint8_t APPSKEY[16] = APP_S_KEY;
static const uint32_t DEVADDR = DEV_ADDR;
#elif
#define _NAME_ "Pengy-???"
static const uint8_t NWKSKEY[16] = { 0x00, 0x00, 0x00, 0x00, 0x00, 0x00, 0x00, 0x00, 0x00, 0x00, 0x00, 0x00, 0x00, 0x00, 0x00, 0x00 };
static const uint8_t APPSKEY[16] = { 0x00, 0x00, 0x00, 0x00, 0x00, 0x00, 0x00, 0x00, 0x00, 0x00, 0x00, 0x00, 0x00, 0x00, 0x00, 0x00 };
static const uint32_t DEVADDR = 0x00000000;
#endif

void os_getArtEui (u1_t* buf) { }
void os_getDevEui (u1_t* buf) { }
void os_getDevKey (u1_t* buf) { }

const lmic_pinmap lmic_pins = 
{
    .nss = LORA_SPI_SS,
    .rxtx = LMIC_UNUSED_PIN,
    .rst = LORA_RST,
    .dio = {LORA_DIO0, LORA_DIO1, LMIC_UNUSED_PIN},
};

unsigned int loops = 0;
uint8_t data[18];

void wait(unsigned long d)
{
    unsigned long b_ = micros();
    unsigned long e_ = d;

    while (e_ > 0)
    {
        yield();
        while ( e_ > 0 && (micros() - b_) >= 1000)
        {
            e_--;
            b_ += 1000;
        }
    }
}

void onEvent (ev_t ev)
{ 
    LOG << F("[") << millis() << F("] LoRa - ") << ev << endl; 
}

void handlePM()
{
    LOG << F("PM") << endl;
    
    // LED on
    digitalWrite(LED_PIN, HIGH);

    //WorkingStateResult sdsStarting = 
    sds.wakeup();
    //LOG << F("  waking up - ") << sdsStarting.statusToString() << endl;

    wait(30000);

    float fpmMin=3.4028235E+38, fpmMax=-3.4028235E+38;
    float rpmMin=3.4028235E+38, rpmMax=-3.4028235E+38;
    int pmCount = 0;

    for (int l=0; l<7; l++)
    {
        PmResult pm = sds.queryPm();
        if (pm.isOk()) 
        {
            //LOG << F(" (") << (l+1) << F(")   fPM=") << pm.pm25 << F("   rPM=") << pm.pm10 << endl;

            fpmCummulative += pm.pm25;
            if (pm.pm25 < fpmMin) fpmMin = pm.pm25;
            if (pm.pm25 > fpmMax) fpmMax = pm.pm25;
            
            rpmCummulative += pm.pm10;
            if (pm.pm10 < rpmMin) rpmMin = pm.pm10;
            if (pm.pm10 > rpmMax) rpmMax = pm.pm10;                

            pmCount++;
            countAQCummulative++;
        }
        /*
        else 
        {
          LOG << F(" (") << (l+1) << F(") X   ") << pm.statusToString() << endl;
        }
        */
        wait(1000);
    }            
    
    //LOG << "cnt " << pmCount << endl;
    //LOG << "fpm m " << fpmMin << " M " << fpmMax << endl;
    //LOG << "rpm m " << rpmMin << " M " << rpmMax << endl;

    if (pmCount > 2)
    {
        fpmCummulative = fpmCummulative - fpmMax - fpmMin;
        rpmCummulative = rpmCummulative - rpmMax - rpmMin;
        countAQCummulative = countAQCummulative - 2;
    }
    
    fpm = 1.0 * fpmCummulative / countAQCummulative; // 0.7
    rpm = 1.0 * rpmCummulative / countAQCummulative; // 0.7
    
    //WorkingStateResult sdsSleeping = 
    sds.sleep();
    //LOG << F("   sleeping - ") << (sdsSleeping.statusToString()) << endl;
    
    // LED off
    digitalWrite(LED_PIN, LOW);
}



// Normalization

void normalizeNoise()
{
    noise = CAL_NOISE_1 * log(noise) + CAL_NOISE_0;
}

void normalizeTHP()
{
    temperature = CAL_TEMPERATURE_1 * temperature + CAL_TEMPERATURE_0;
    humidity    = CAL_HUMIDITY_1    * humidity    + CAL_HUMIDITY_0;
    pressure    = CAL_PRESSURE_1    * pressure    + CAL_PRESSURE_0;
}

void normalizeGas()
{
    concetrationCO  = CAL_GAS_CO_1  * pow(concetrationCO,  CAL_GAS_CO_0);
    concetrationNH3 = CAL_GAS_NH3_1 * pow(concetrationNH3, CAL_GAS_NH3_0);
    concetrationNO2 = CAL_GAS_NO2_1 * pow(concetrationNO2, CAL_GAS_NO2_0);
}

void normalizePM()
{
    rpm = (CAL_RPM_2 * rpm + CAL_RPM_1) * rpm + CAL_RPM_0;
    fpm = (CAL_FPM_2 * fpm + CAL_FPM_1) * fpm + CAL_FPM_0;
}


// Setup & Loop
void setup()
{
    pinMode(LED_PIN, OUTPUT);
    digitalWrite(LED_PIN, HIGH);
  
    while (!Serial && millis() < 10000);
    Serial.begin(115200);

    delay(10);
    LOG << endl << endl  << F(_NAME_) << " - " << F(__DATE__) << " " << F(__TIME__) << endl << "#" << endl << endl;

    // init air quiality sensor
    //LOG << F("Setup Air Quality sensor") << endl;
    sds.begin();
    //ReportingModeResult modeResult = 
    sds.setQueryReportingMode();
    //LOG << F("   Querying : ") << modeResult.statusToString() << endl;

    /*
    LOG << F("   mode     : ") << sds.queryReportingMode().statusToString() << endl;
    LOG << F("   firmware : ") << sds.queryFirmwareVersion().statusToString() << endl;
    LOG << F("   state    : ") << sds.queryWorkingState().statusToString() << endl;
    LOG << F("   querying : ") << sds.setQueryReportingMode().statusToString() << endl;
    */
        
    // init wire
    wireSetup();

    // Init LoRa
    os_init();
    LMIC_reset();

    LMIC_setSession (0x13, DEVADDR, (uint8_t*)NWKSKEY, (uint8_t*)APPSKEY);

    LMIC_setupChannel(0, 868100000, DR_RANGE_MAP(DR_SF12, DR_SF7),  BAND_CENTI);      // g-band
    LMIC_setupChannel(1, 868300000, DR_RANGE_MAP(DR_SF12, DR_SF7B), BAND_CENTI);      // g-band
    LMIC_setupChannel(2, 868500000, DR_RANGE_MAP(DR_SF12, DR_SF7),  BAND_CENTI);      // g-band
    LMIC_setupChannel(3, 867100000, DR_RANGE_MAP(DR_SF12, DR_SF7),  BAND_CENTI);      // g-band
    LMIC_setupChannel(4, 867300000, DR_RANGE_MAP(DR_SF12, DR_SF7),  BAND_CENTI);      // g-band
    LMIC_setupChannel(5, 867500000, DR_RANGE_MAP(DR_SF12, DR_SF7),  BAND_CENTI);      // g-band
    LMIC_setupChannel(6, 867700000, DR_RANGE_MAP(DR_SF12, DR_SF7),  BAND_CENTI);      // g-band
    LMIC_setupChannel(7, 867900000, DR_RANGE_MAP(DR_SF12, DR_SF7),  BAND_CENTI);      // g-band
    LMIC_setupChannel(8, 868800000, DR_RANGE_MAP(DR_FSK,  DR_FSK),  BAND_MILLI);      // g2-band

    LMIC_setLinkCheckMode(0);

    LMIC.dn2Dr = DR_SF9;
    LMIC_setDrTxpow(DR_SF7,14);

    digitalWrite(LED_PIN, LOW);
}
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

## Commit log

2020-12-20 luftdaten.info: updated v.15 new api new sensor id tempalte logstash bump python 3.8
2020-12-24 rename to sensor.community
2021-01-18 LMIC-Arduino depriciated
2021-05-12 badge device data saparation
2021-05-13 light effects with timer
2021-05-21 noise sampling tweaks coloring EAQI
    [pengy.cpp]
